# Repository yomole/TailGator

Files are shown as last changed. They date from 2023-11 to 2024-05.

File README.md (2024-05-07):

# [TailGator](https://github.com/yomole/TailGator)

> [!NOTE]
> - If you are a student who has requested to continue this project as part of senior design for MIL, please fork this repository for your project and update the submodules link inside of the MIL Electrical Team SubjuGator 9 repository.
> - Feel free to reach out to the project's hardware designer (Yovany Molina) for any questions you might have.
> - Assembled boards and spare PCBs and parts may still be in the lab.
> - Good Luck!

# Introduction

The TailGator Interconnect System (TGIS) project provides a modular connection system and standard for easily connecting, replacing, and upgrading underwater robotics hardware in space-constrained robotics designs. 
Several other standards exist for modular electronics hardware, including:

- [Adafruit Feather Specification](https://learn.adafruit.com/adafruit-feather/feather-specification)
- [Sparkfun MicroMod Specification](https://www.sparkfun.com/micromod)
- [Arduino Shield Specificaton](https://learn.sparkfun.com/tutorials/arduino-shields-v2)
- [PCI-e Specification](https://pcisig.com/)

However, no single standard contains the pin density, physical dimensions, signal integrity, power delivery, and cost effectiveness we are looking for. The TailGator Interconnect System aims to solve this problem for the Machine Intelligence Laboratories' [SubjuGator 9 Autonomous Underwater Vehicle](http://subjugator.org/?page_id=3390) platform while making the design open source to help the robotics community.

Our production release demonstration can be found here: https://youtu.be/vW_x0FsKn2Q

# Electrical Specifications

The current design of TGIS can supply:
- 3.3V @ 4A (13.3W)
- 5V @ 4A (20W)

Reserved lines may be used to supplement the 3.3V or 5V lines. Board designs may also include a 5V to 3.3V LDO regulator to suppliment the 3.3V line on a specific board in the system.

## Pinout

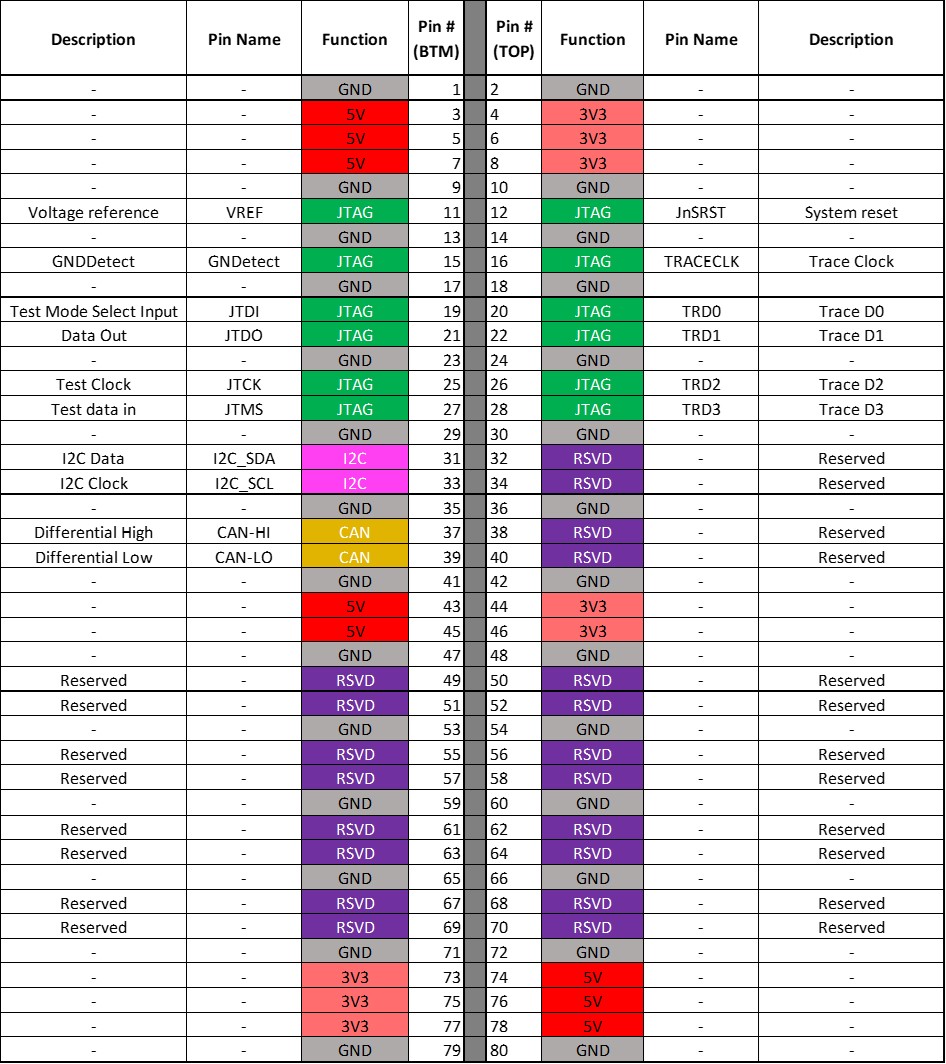
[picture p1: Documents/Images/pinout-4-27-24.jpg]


# Hardware

Currently, the project contains Altium schematics and layouts for three boards used for power, communications, and alpha-build testing. These can be found in the `PCB/TailGator Interconnect System` folder:
- Power Input Board (`TGIS Main`) **V1**: Accepts power for the 3.3V and 5V rails used for TGIS boards while regulating it against reverse polarity and overvoltage. Also offers overcurrent protection.
- USB to CAN Board (`TGIS USB to CAN`) **V1**: Transcribes USB serial messages into CAN packets that are sent to all connected boards in the TGIS system. This board has inputs for JTAG, external CAN connections using RJ45, and SWD for debugging the board's RP2040 microcontroller.
- Breakout Board (`TGIS Breakout`) **V1**: Allows access to the TGIS connector lines using typical 0.1" (2.54mm) headers. This is going to be used for alpha-build testing of the different features currently implemented across all produced boards.  

Other folders contain incomplete designs for other planned boards.

## Documentation

For those without access to [Altium Designer](https://www.altium.com/altium-designer), [Altium Designer Viewer](https://www.altium.com/altium-designer-viewer), or similar compatible applications, documentation for each produced hardware design is available under the `Project Outputs` folder for each respective project. Links are also provided here for convienience:
- [Power Distribution Board](<PCB/TailGator Interconnect System/TGIS Main/Project Outputs for TGIS Power Distribution Board/TGIS.PDF>)
- [USB to CAN Board](<PCB/TailGator Interconnect System/TGIS USB to CAN/TGIS USB to CAN/Project Outputs for TGIS USB to CAN/TGIS.PDF>)
- [System Status Board](<PCB/TailGator Interconnect System/TGIS System Status/Project Outputs for TGIS System Status/TGIS.PDF>)
- [Termination Board](<PCB/TailGator Interconnect System/TGIS CAN Termination/Project Outputs for TGIS CAN Termination/TGIS.PDF>)
- [Breakout Board](<PCB/TailGator Interconnect System/TGIS Breakout/TGIS Breakout/Project Outputs for TGIS Breakout/TGIS.PDF>)
- Handwritten [Development Notes](<Documents/Research/Backplane.pdf>) taken throughout the project are also available in PDF format.

## Libraries

The Altium libraries used for the project have been compiled into an integrated library for use with your own projects involving the TailGator Interconnect System. You may find `TGIS.intlib` file in `PCB/Library/Project Outputs for TGIS`.

## Simulations

There are LTSpice simulations for some parts of the circuits we designed. Libraries used are included.

- `3V3_Protection.asc` is an LTSpice simulation of the 3.3V protection circuits in the Power Input Board. This circuit contains reverse polarity protection, overcurrent protection, and overvoltage protection.
- `5V_Protection.asc` is an LTSpice simulation of the 5V protection circuits in the Power Input Board. This circuit contains reverse polarity protection, overcurrent protection, and overvoltage protection.

### LTSpice Libraries

The libraries in the simulations folder are used for some of the components in the LTSpice circuits.

- `fuse2.lib` is a library of fuses compiled by user aurvii based on a fuse model by Helmut Sennewald. It can be found in the [Official LTSpice Support Group](https://groups.io/g/LTspice).
- `st_standard_sensitve_scr` is a library of sensitive and standard SCRs/Thyristors by STMicroelectronics. It can be found [here](https://www.st.com/resource/en/spice_model/standard_sensitive_scr_pspice.zip).
- `Zener_DiodesInc.lib` is a modified version of this [zener diodes library](https://www.diodes.com/productcollection/spicemodels/8345/Zener+Diodes.spice.txt?eid=88) from Diodes Inc with `.ends` statements moved to new lines to appease LTSpice.

All other models used come standard with LTSpiceXVII.

To install these libraries, you must copy and paste them into your LTSpice subcircuit folder. Depending on your version of LTSpice, on Windows machines, this could be:
- `%localappdata%\LTspice\lib\sub`
- `%userprofile%\Documents\LTSpiceXVII\lib\sub`
- `%programfiles%\LTC\LTSpiceXVII\lib\sub`

or other directories.

### Simulation Results

#### 5V_Protection.asc
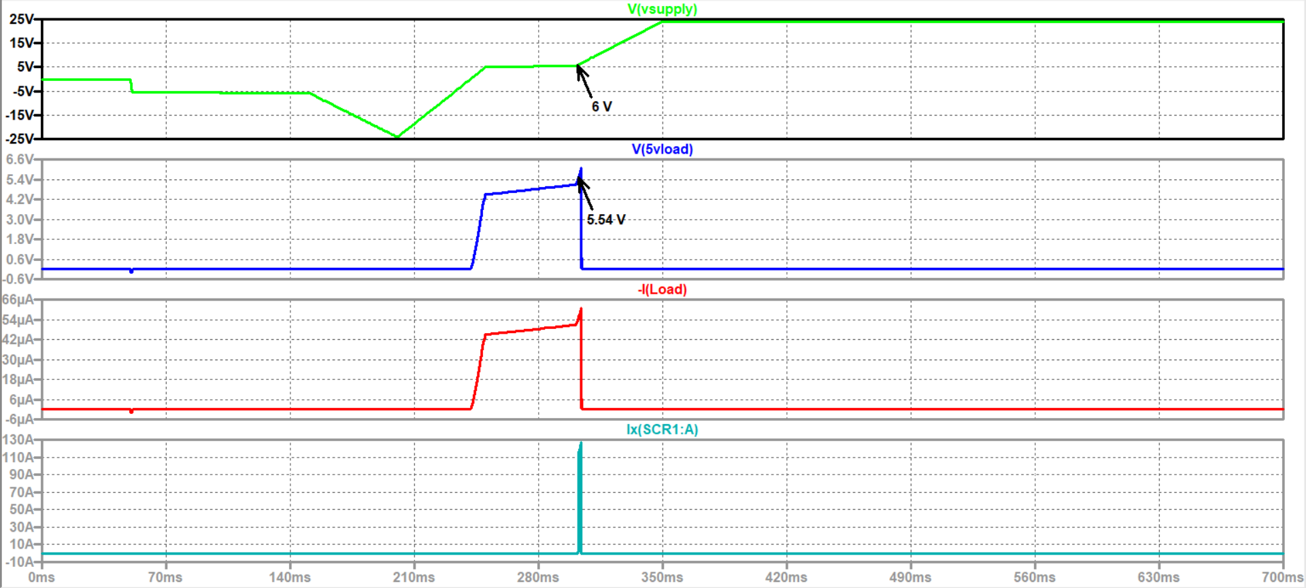
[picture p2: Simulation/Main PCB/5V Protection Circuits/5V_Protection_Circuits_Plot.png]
Plot of 5V protection circuits


#### 3V3_Protection.asc
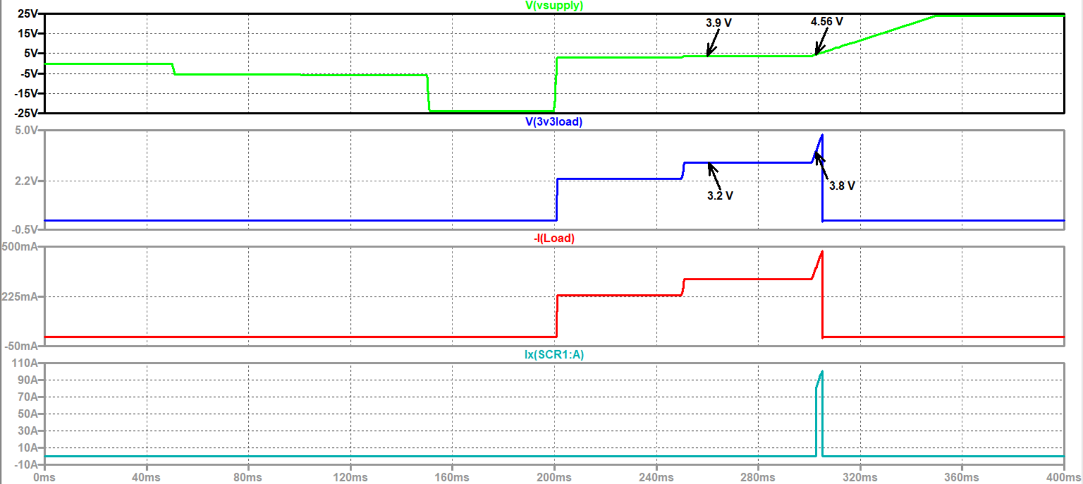
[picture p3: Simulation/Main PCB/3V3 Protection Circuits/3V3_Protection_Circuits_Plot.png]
Plot of 3.3V protection circuits


### Hardware Test Results

### V1

Hardware testing for the power input board was performed using a ODP3122 power supply, DL3021 electric load, and an MSO7014A mixed signal oscilloscope. Most of this equipment was interfaced using python code to send SCPI messages.

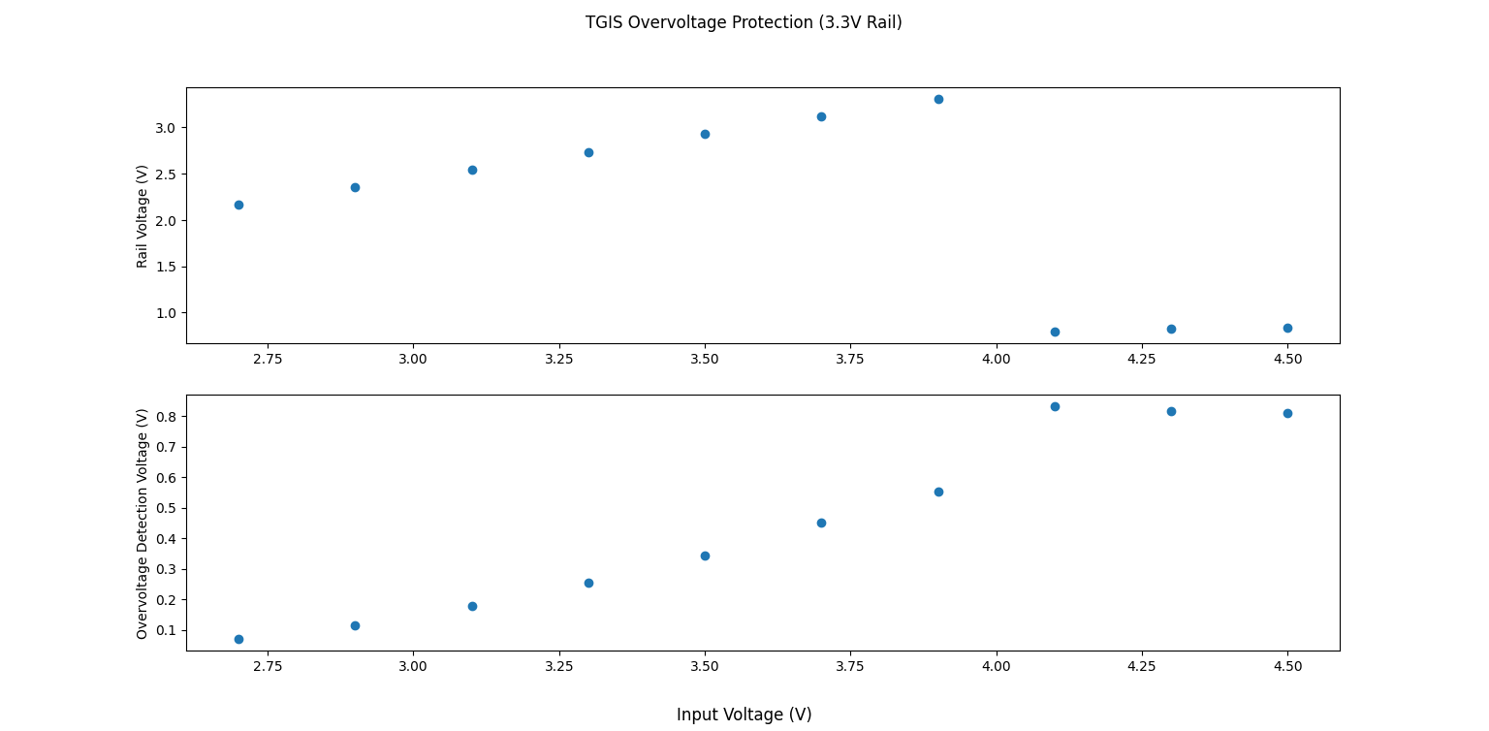
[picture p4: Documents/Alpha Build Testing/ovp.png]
Plot of 3.3V overvoltage protection

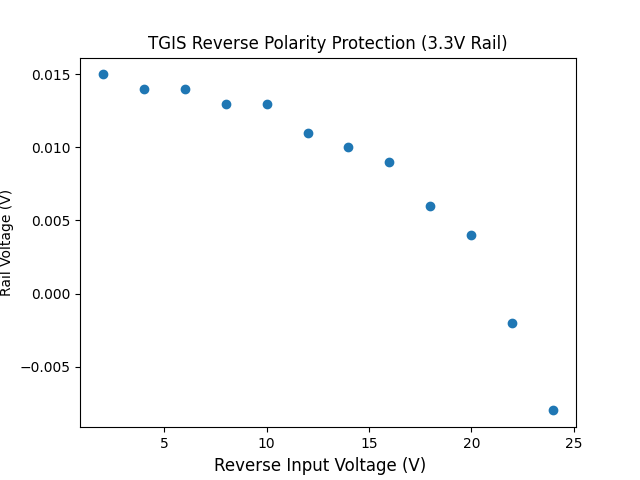
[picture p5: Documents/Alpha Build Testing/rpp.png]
Plot of 3.3V reverse polarity protection


The fuse did work in the overvoltage protection case, but activated after a very long amount of time. We will try to use fast acting automotive fuses in future revisions.

## Known Issues
- The mezzanine connector used has too small of a pitch to be reliably soldered using reflow. We recommend switching to [conan connectors](https://www.digikey.com/en/product-highlight/a/amphenol-fci/conan-lite-1-00-mm-connectors) since they have a slightly larger (1.0mm) pitch. 60 pins should still be enough to have plenty of reserved pins for future expansion.
- The BOM has the wrong SWD connector.
- Some parts on the system status board (like the LEDs) require an active USB connection to function. They should instead be powered from the same source as the RP2040 (which is the selectable power source).
- The reset circuit on the system status board does not function correctly.
- The breakout board should be expanded to have plug and receptacle connections like other boards so it can be used in the front or the back.
- The headers to disable I2C on the termination board should be replaced with 0 ohm resistors that are not placed by default.
- The mounting holes should be M2.5 as MIL has switched to that screw size being the standard for all boards.
- The power distribution board has a higher voltage drop across the protection circuitry, meaning that there is still a problem if bypass mode is used without first checking the input voltage. We recommend keeping the crowbar circuit design from V1.
- CAN signals cannot pass through the USB to CAN board, but can pass through all other boards, including the System Status Board. Further investigation is needed.
- JTAG chaining was never implemented since no microcontrollers on designed boards supported JTAG. They may need buffers between boards for proper operation.
- Some JTAG signals (TRACECLK, TRD*, VREF, GNDDetect, JnSRST) may be omitted from the connector or otherwise tied to a constant value.

# Software
Our work includes the design of firmware for the TGIS's system status board, which can display diagnostic information about the system.

For the production release, the firmware has been fully verified to support all major components on the system status board PCB:
- OLED display, prototyped on the [Adafruit OLED Feather](https://www.adafruit.com/product/4650) and communicating via I2C;
- LIS3DH IMU (tested previously in the Alpha Build);
- Micro SD card reader, using 4-pin SPI to communicate;
- Leak alarm, a piezo buzzer activated via GPIO; and
- Leak detector, prototyped via a push button connected to an input pin on the Feather RP2040.

All of the above components have been updated to work concurrently on `embedded-hal` version 1.0.

We are using the [RTIC Framework](https://rtic.rs/) to provide concurrent sensor access and display interfacing. This app can be seen in the `RTIC_App` directory of this repo.

## Installation

Prerequisites:
- Working Rust toolchain for embedded development on the RP2040 (e.g., capable of running the Embedded Rust lab code)
- Adafruit Feather RP2040
- All of the above major components (LIS3DH, OLED, SD card reader) and connectivity to the feather (jumper cables and/or Feather boards)
- (Note: for testing the CAN demonstration, a pair of RP2040 devices each attached to a CAN transceiver via two GPIO pins for the Rx and Tx lines is required. One device must be flashed with the transmitter code--`CAN_Demo/CAN_Transmsit`--and the other with the receiver code--`CAN_Demo/CAN_Receive`. The transmitter should have a digital input component such as a button attached to the appropriate GPIO pin, and the receiver must be attached to a computer via USB where `minicom` shoud be run to inspect serial output at baud rate 115200.)

Clone this repository: `https://github.com/yomole/TailGator.git`, then open the app (`RTIC_App`) and inspect the code.

From within the app, run `cargo run` from within the `RTIC_App` directory with your Feather RP2040 connected to a debug probe over SWD. This will automatically flash the software to the Feather and run the program with rich debug output.

Alternatively, in .cargo/config, you can set the runner to be `elf2uf2-rs` instead of `probe-rs` by commenting and uncommenting the appropriate lines. `cargo run` will then work with a Feather RP2040 set to receive a UF2 file, but of course you will need a debug probe to see the output.

## Known Issues
1. CAN bus communication has not yet been integrated with the system status board firmware due to a need for more up-to-date CAN drivers.
2. SWD port on the system status board is nonfunctional, and so debug output can only be demonstrated on the testbench via a Feather RP2040 and appropriately wired components. This may require reconfiguring GPIO pin selection for the devices under test.

# Time Tracking

[Google Sheet](https://docs.google.com/spreadsheets/d/1ABE5ELdahlYolHOQ2TSzXDdkT7J0JBhl6qDKFItKDu4/)

# Ackowledgements

This project is made in collaboration with:
- [Machine Intelligence Laboratory](https://mil.ufl.edu/)

Thanks to [Carsten](https://github.com/shulltronics) for supporting our switch to the Rust RTIC framework and for providing a secondary Adafruit Feather RP2040 to use as an SWD debugger, as well as an OLED display and associated connector cable.

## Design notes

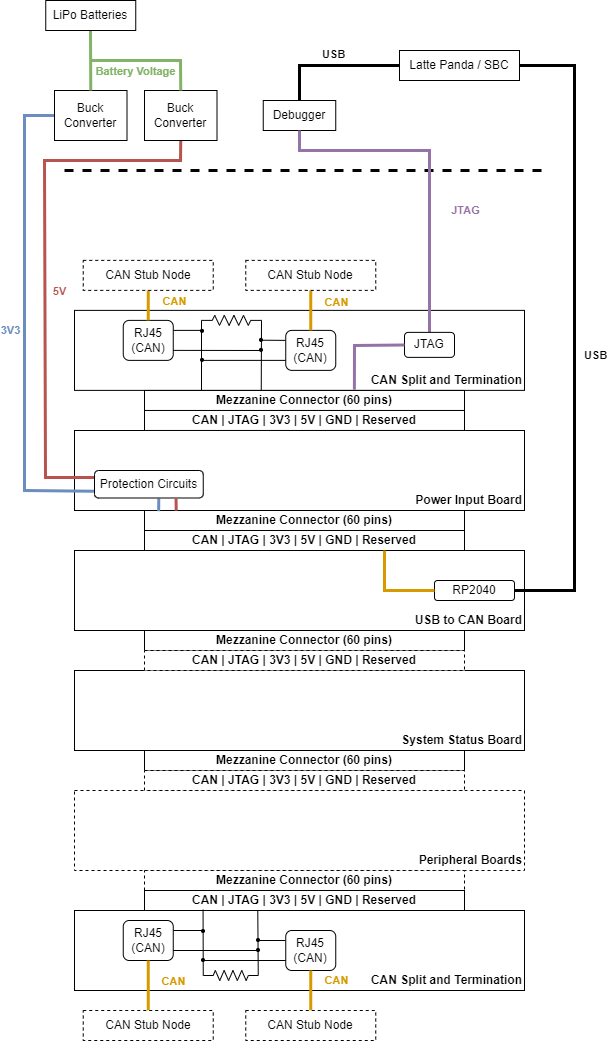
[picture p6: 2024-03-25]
Documents/Images/Block Diagram.png

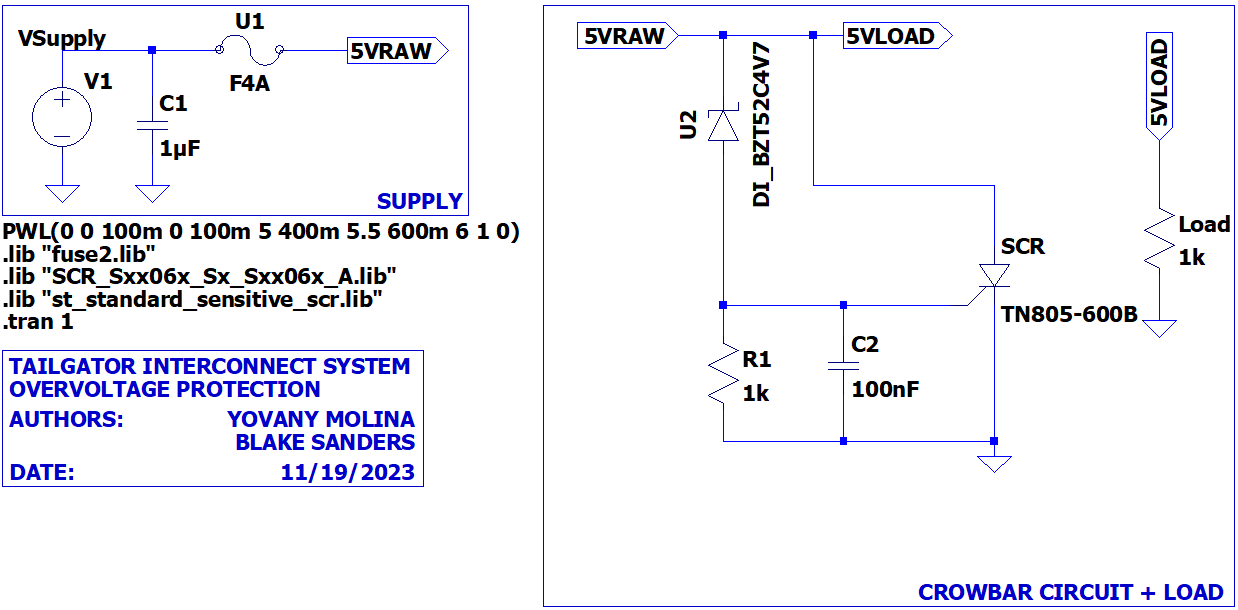
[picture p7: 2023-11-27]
Simulation/Main PCB/5V Protection Circuits/5V_OVP_Circuit.png

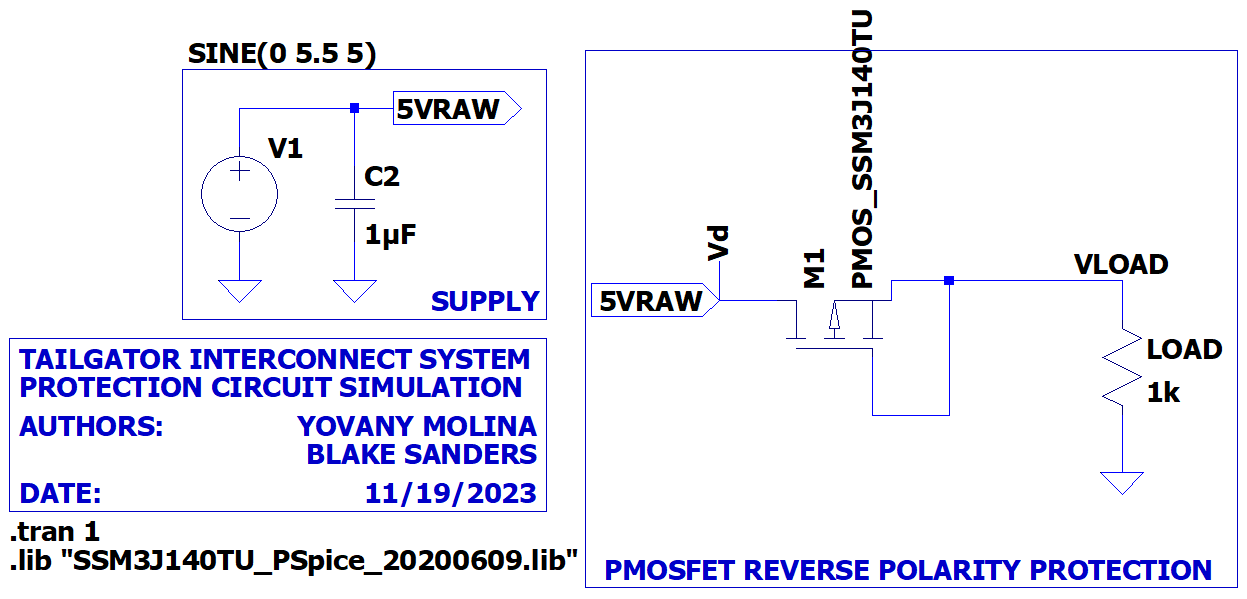
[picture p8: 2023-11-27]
Simulation/Main PCB/5V Protection Circuits/5V_RPP_Circuit.png

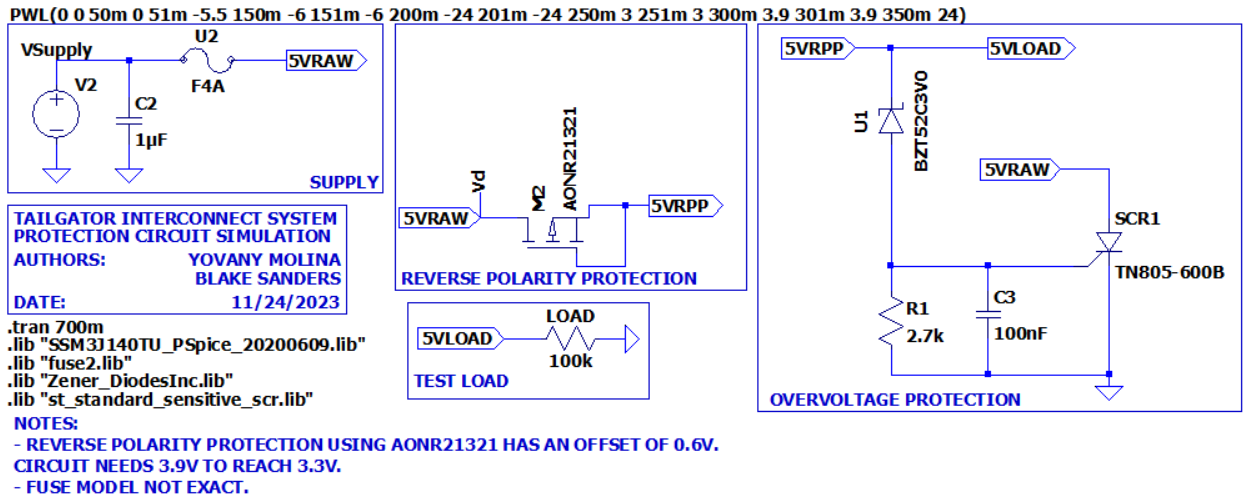
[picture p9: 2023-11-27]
Simulation/Main PCB/3V3 Protection Circuits/3V3_Protection_Circuits.png

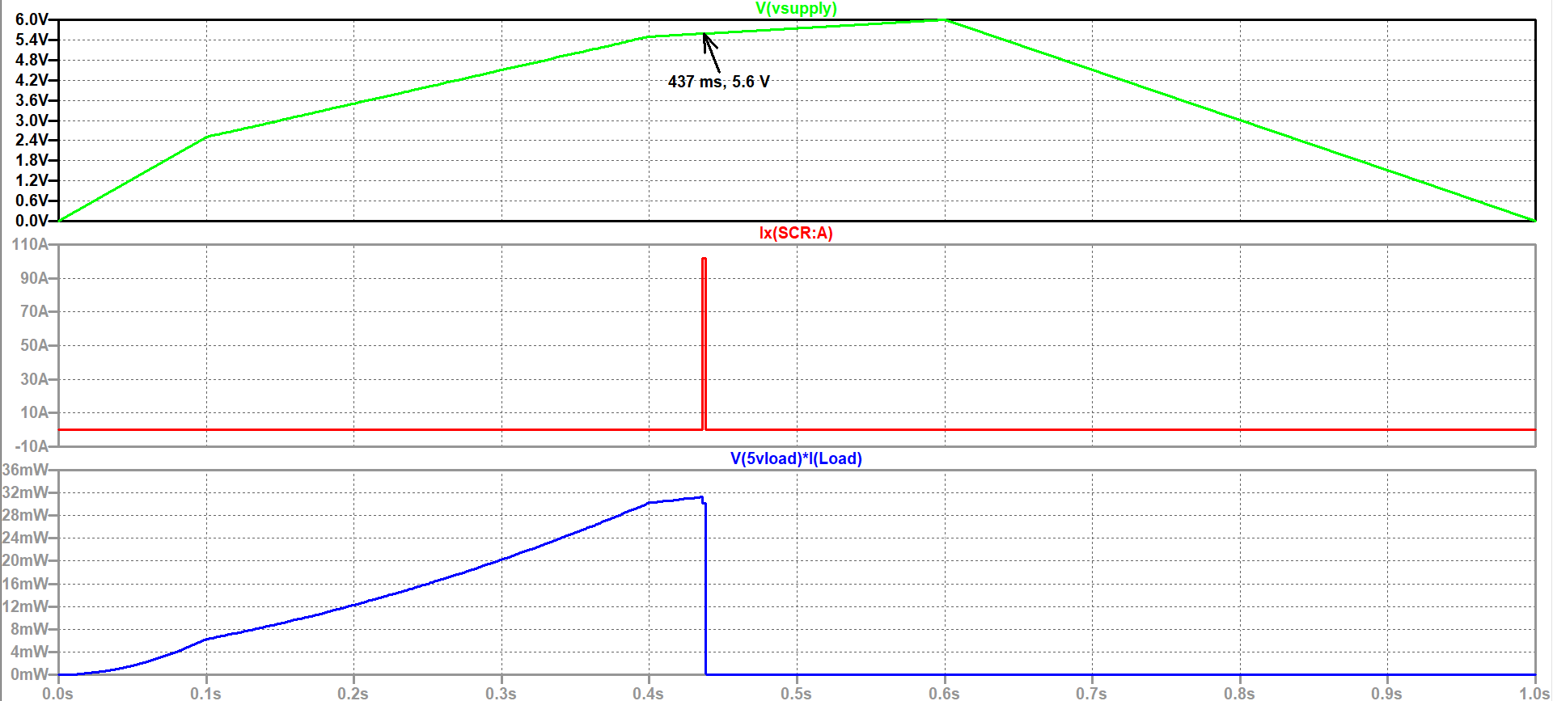
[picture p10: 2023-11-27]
Simulation/Main PCB/5V Protection Circuits/5V_OVP_Plot.png

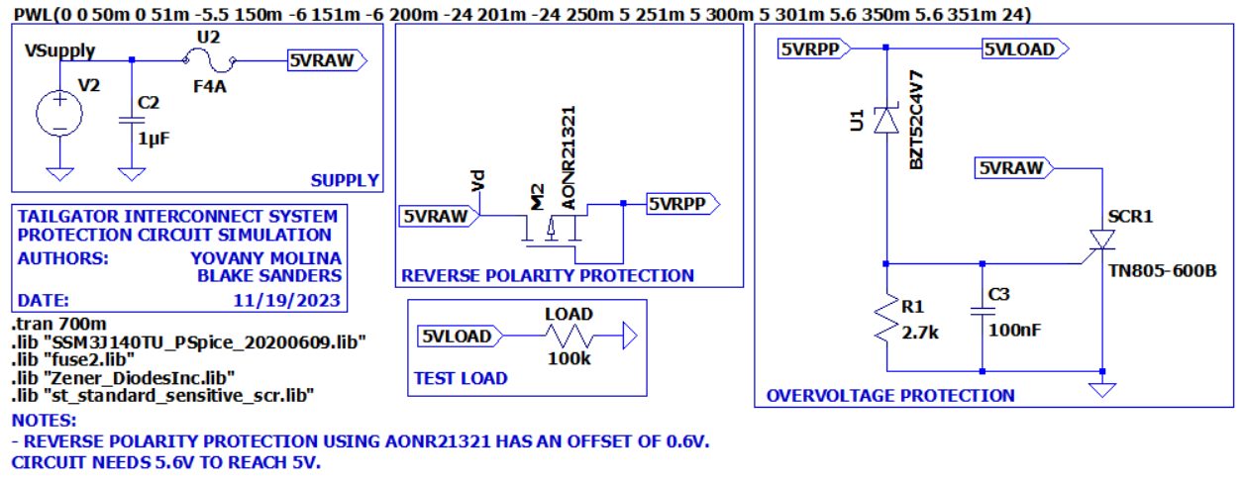
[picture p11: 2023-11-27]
Simulation/Main PCB/5V Protection Circuits/5V_Protection_Circuits.png

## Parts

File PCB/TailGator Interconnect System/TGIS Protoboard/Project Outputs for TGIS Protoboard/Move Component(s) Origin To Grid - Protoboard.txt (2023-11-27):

Move Component(s) Origin to Grid
Filename     : C:\Users\molyo\OneDrive\Desktop\MIL\TailGator\PCB\TailGator Interconnect System\TGIS Protoboard\Protoboard.PcbDoc
Date         : 11/7/2023
Time         : 5:04:12 PM
Time Elapsed : 00:00:00

    Component J?-RAILS (3960mil,2960mil) on Top Layer - Component origin is already ON grid. - Component pads are OFF grid. No action taken.
    SOIC Component J?-10144517-063802LF (3960mil,1460mil) on Top Layer - Component origin is already ON grid. - Component pads are OFF grid. No action taken.
count : 2

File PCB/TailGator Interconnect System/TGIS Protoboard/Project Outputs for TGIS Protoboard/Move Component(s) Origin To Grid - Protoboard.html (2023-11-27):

Date: | 11/7/2023
Time: | 5:04:12 PM
Elapsed Time: | 00:00:00
Filename: | C:\Users\molyo\OneDrive\Desktop\MIL\TailGator\PCB\TailGator Interconnect System\TGIS Protoboard\Protoboard.PcbDoc
Component J?-RAILS (3960mil,2960mil) on Top Layer - Component origin is already ON grid. - Component pads are OFF grid. No action taken.
SOIC Component J?-10144517-063802LF (3960mil,1460mil) on Top Layer - Component origin is already ON grid. - Component pads are OFF grid. No action taken.

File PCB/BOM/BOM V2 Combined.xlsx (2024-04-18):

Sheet: COMBINED PT2
Line # | Project Designator | Quantity | Supplier Order Qty 1 | Manufacturer | Manufacturer Part Number | Supplier Part Number | STAT?
1 | *PDB* C1, C2 | *TERM* C1, C2 | *U2C* C2, C3, C4, C5, C6, C7, C8, C9, C11, C12, C13, C16, C17 | *STAT* C2, C3, C4, C5, C6, C7, C8, C9, C11, C12, C13, C18, C19, C20, C21, C22 | 33 | 35 | Yageo | CC0603KRX7R7BB104 | 311-1088-1-ND | YES
2 | *PDB* D1 | 1 | 1 | Diodes | BZT52C3V0-7-F | BZT52C3V0-FDICT-ND | NO
3 | *PDB* D3 | 1 | 1 | Diodes | BZT52C4V7-13-F | BZT52C4V7-13-FDICT-ND | NO
4 | *PDB* D5 | *U2C* D2, LED2 | *STAT* D3, LED2 | 5 | 5 | Wurth Electronics | 150060YS75000 | 732-4981-1-ND | YES
5 | *PDB* D6 | *U2C* LED1 | *STAT* D1, LED1 | 4 | 4 | Wurth Electronics | 150060RS75000 | 732-4978-1-ND | YES
6 | *PDB* J1 | *TERM* J1 | *U2C* J1 | *STAT* J1 | 4 | 5 | Amphenol ICC / FCI | 10144517-081802LF | 609-5437-1-ND | YES
7 | *PDB* J2 | 1 | 1 | Amphenol Communications Solutions | 10144518-081802LF | 609-5453-1-ND | NO
8 | *PDB* J3, J4 | 2 | 2 | TE Connectivity | 1877285-2 | A99845-ND | NO
9 | *PDB* Q1, Q2 | 2 | 2 | Alpha & Omega Semiconductor | AONR21321 | 785-1797-1-ND | NO
10 | *PDB* R1, R2 | 2 | 2 | Yageo | RC0603FR-073K3L | 311-3.30KHRCT-ND | NO
11 | *PDB* R3, R4 | *TERM* R1, R2, R3, R4, R5, R6 | *U2C* R4, R6, R8, R13, R14 | *STAT* R4, R6, R8, R9, R10, R11, R12, R15 | 21 | 27 | Yageo | RC0603FR-071KL | 311-1.00KHRCT-ND | YES
12 | *TERM* C3, C4 | 2 | 4 | Yageo | CC0603JPX7R9BB472 | 13-CC0603JPX7R9BB472CT-ND | NO
13 | *TERM* J2 | *U2C* J2 | *STAT* J2 | 3 | 4 | Amphenol Communications Solutions | 10144518-083802LF | 609-5455-1-ND | YES
14 | *TERM* J3, J4, J5, J6 | 4 | 8 | Molex | 0353630260 | WM18931-ND | NO
15 | *TERM* R7, R8, R13, R14 | 4 | 8 | Yageo | RC0603JR-070RL | 311-0.0GRCT-ND | NO
16 | *TERM* R9, R10, R11, R12 | 4 | 8 | Yageo | RC0603FR-0760R4L | 311-60.4HRCT-ND | NO
17 | *TERM* U1, U2 | 2 | 4 | NXP Semiconductors | PCA9515ADP.118 | 568-1032-1-ND | NO
18 | *U2C* J5 | 1 | 1 | Adam Equipment | PH2RA-08-UA | 2057-PH2RA-08-UA-ND | NO
19 | *STAT* J5 | 1 | 1 | GCT | MEM2052-00-195-00-A | 2073-MEM2052-00-195-00-ACT-ND | YES
20 | *STAT* J6 | 1 | 1 | Adafruit Industries | 4650 | 1528-4650-ND | YES
21 | *STAT* J7 | 1 | 1 | Molex | 35363-0360 | WM18932-ND | YES
22 | *STAT* J8 | 1 | 1 | Molex | 35363-0460 | WM18933-ND | YES
23 | *STAT* Q1 | 1 | 1 | Diodes | DMP3056L-7 | DMP3056L-7DICT-ND | YES
24 | *STAT* Q2 | 1 | 1 | ON Semiconductor / Fairchild | 2N7002W | 2N7002WCT-ND | YES
25 | *STAT* R13, R14 | 2 | 2 | Yageo | RC0603FR-0710KL | 311-10.0KHRCT-ND | YES
26 | *STAT* R17, R18 | 2 | 2 | Stackpole Electronics | RMCF0603JT10K0 | RMCF0603JT10K0CT-ND | YES
27 | *STAT* U4 | 1 | 1 | CUI Devices | CMI-9705-0380-SMT-TR | 102-CMI-9705-0380-SMT-CT-ND | YES
28 | *STAT* U5 | 1 | 1 | Diodes | 74LVC1G17SE-7 | 74LVC1G17SE-7CT-ND | YES
29 | *STAT* U7 | 1 | 1 | STMicroelectronics | LIS3DHTR | 497-10613-1-ND | YES
30 | *U2C* C1, C10, C19, C20 | *STAT* C1, C10, C16, C17 | 8 | 8 | Yageo | CC0603KRX7R7BB105 | 311-1446-1-ND | YES
31 | *U2C* C14, C15 | *STAT* C14, C15 | 4 | 4 | Yageo | CC0603JRNPO9BN270 | 311-1063-1-ND | YES
32 | *U2C* D1 | *STAT* D2 | 2 | 2 | Wurth Electronics | 150060VS75000 | 732-4980-1-ND | YES
33 | *U2C* J3 | *STAT* J3 | 2 | 2 | Global Connector Technology | USB4105-GF-A | 2073-USB4105-GF-ACT-ND | YES
34 | *U2C* J4 | *STAT* J4 | 2 | 2 | CNC Tech | 3221-10-0300-00 | 1175-1735-ND | YES
35 | *U2C* Q1, Q2 | *STAT* Q3, Q4 | 4 | 4 | ON Semiconductor | MMUN2235LT1G | MMUN2235LT1GOSCT-ND | YES
36 | *U2C* R1, R2 | *STAT* R1, R2 | 4 | 4 | Yageo | RC0603FR-075K1L | 311-5.10KHRCT-ND | YES
37 | *U2C* R5, R7 | *STAT* R5, R7 | 4 | 4 | Yageo | RC0603FR-0727R4L | 311-27.4HRCT-ND | YES
38 | *U2C* R11, R12 | *STAT* R16, R19, R20 | 5 | 5 | Yageo | RC0603FR-07270RL | 311-270HRCT-ND | YES
39 | *U2C* SW1, SW2 | *STAT* SW1, SW2 | 4 | 4 | ITT C&K | PTS810SJK250SMTRLFS | CKN10503CT-ND | YES
40 | *U2C* SW3 | *STAT* SW3 | 2 | 2 | ITT C&K | JS202011SCQN | 401-2002-1-ND | YES
41 | *U2C* U1 | *STAT* U1 | 2 | 2 | Raspberry Pi | SC0914(13) | 2648-SC0914(13)CT-ND | YES
42 | *U2C* U2 | *STAT* U2 | 2 | 2 | Winbond | W25Q128JVSIQ TR | W25Q128JVSIQCT-ND | YES
43 | *U2C* U3 | *STAT* U6 | 2 | 2 | Texas Instruments | TCAN1057ADDFRQ1 | 296-TCAN1057ADDFRQ1CT-ND | YES
44 | *U2C* U4 | *STAT* U3 | 2 | 2 | Texas Instruments | TLV75733PDRVR | 296-49281-1-ND | YES
45 | *U2C* X1 | *STAT* X1 | 2 | 2 | Abracon | ABLS-12.000MHZ-B2-T | 535-9067-1-ND | YES

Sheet: CHECK
Index | Quantity | Part Number | Manufacturer Part Number | Description | Customer Reference | Available | Backorder | Unit Price | Extended Price USD
1 | 15 | F988-ND | 0297004.WXNV | FUSE AUTOMOTIVE 4A 32VDC BLADE |  | 15 | 0 | 0.325 | 4.88
2 | 2 | W25Q128JVSIQCT-ND | W25Q128JVSIQ TR | IC FLASH 128MBIT SPI/QUAD 8SOIC | STAT V1 U2 | 2 | 0 | 1.78 | 3.56
3 | 2 | 497-10613-1-ND | LIS3DHTR | ACCEL 2-16G I2C/SPI 16LGA | STAT V1 U7 | 2 | 0 | 2.26 | 4.52
4 | 2 | 535-9067-1-ND | ABLS-12.000MHZ-B2-T | CRYSTAL 12.0000MHZ 18PF SMD | STAT V1 X1 | 2 | 0 | 0.24 | 0.48
5 | 2 | 296-TCAN1057ADDFRQ1CT-ND | TCAN1057ADDFRQ1 | IC TRANSCEIVER HALF 1/1 TSOT23-8 | STAT V1 U6 | 2 | 0 | 0.83 | 1.66
6 | 2 | 2648-SC0914(13)CT-ND | SC0914(13) | IC MCU 32B EXT MEM 56QFN RP2040 | STAT V1 U1 | 2 | 0 | 0.7 | 1.40
7 | 2 | 102-CMI-9705-0380-SMT-CT-ND | CMI-9705-0380-SMT-TR | BUZZER MAGNETIC 3V 9.7X9.7MM SMD | STAT V1 U4 | 2 | 0 | 1.77 | 3.54
8 | 2 | 74LVC1G17SE-7CT-ND | 74LVC1G17SE-7 | IC BUF NON-INVERT 5.5V SOT353 | STAT V1 U5 | 2 | 0 | 0.27 | 0.54
9 | 2 | 296-49281-1-ND | TLV75733PDRVR | IC REG LINEAR 3.3V 1A 6WSON | STAT V1 U3 | 2 | 0 | 0.46 | 0.92
10 | 2 | 401-2002-1-ND | JS202011SCQN | SWITCH SLIDE DPDT 300MA 6V | STAT V1 SW3 | 2 | 0 | 0.73 | 1.46
11 | 4 | MMUN2235LT1GOSCT-ND | MMUN2235LT1G | TRANS PREBIAS NPN 50V SOT23-3 | STAT V1 Q3, Q4 | 4 | 0 | 0.13 | 0.52
12 | 2 | WM18933-ND | 0353630460 | CONN HEADER R/A 4POS 2MM | STAT V1 J8 | 2 | 0 | 0.64 | 1.28
13 | 4 | CKN10503CT-ND | PTS810 SJK 250 SMTR LFS | SWITCH TACTILE SPST-NO 0.05A 16V | STAT V1 SW1, SW2 | 4 | 0 | 0.34 | 1.36
14 | 10 | RMCF0603JT10K0CT-ND | RMCF0603JT10K0 | RES 10K OHM 5% 1/10W 0603 | STAT V1 R17, R18 | 10 | 0 | 0.021 | 0.21
15 | 1 | 1528-4650-ND | 4650 | ADAFRUIT FEATHERWING OLED - 128X | STAT V1 J6 | 1 | 0 | 14.95 | 14.95
16 | 2 | DMP3056L-7DICT-ND | DMP3056L-7 | MOSFET P-CH 30V 4.3A SOT23 | STAT V1 Q1 | 2 | 0 | 0.41 | 0.82
17 | 10 | 311-270HRCT-ND | RC0603FR-07270RL | RES 270 OHM 1% 1/10W 0603 | STAT V1 R16, R19, R20 | 10 | 0 | 0.019 | 0.19
18 | 16 | 311-1.00KHRCT-ND | RC0603FR-071KL | RES 1K OHM 1% 1/10W 0603 | STAT V1 R4, R6, R8, R9, R10, R11, R12, R15 | 16 | 0 | 0.019 | 0.30
19 | 10 | 311-27.4HRCT-ND | RC0603FR-0727R4L | RES 27.4 OHM 1% 1/10W 0603 | STAT V1 R5, R7 | 10 | 0 | 0.02 | 0.20
20 | 10 | 311-5.10KHRCT-ND | RC0603FR-075K1L | RES 5.1K OHM 1% 1/10W 0603 | STAT V1 R1, R2 | 10 | 0 | 0.019 | 0.19
21 | 2 | 2N7002WCT-ND | 2N7002W | MOSFET N-CH 60V 310MA SC70 | STAT V1 Q2 | 2 | 0 | 0.43 | 0.86
22 | 2 | WM18932-ND | 0353630360 | CONN HEADER R/A 3POS 2MM | STAT V1 J7 | 2 | 0 | 0.43 | 0.86
23 | 2 | 2073-MEM2052-00-195-00-ACT-ND | MEM2052-00-195-00-A | MICRO SD PUSH PUSH, OPEN, SMT, 1 | STAT V1 J5 | 2 | 0 | 1.2 | 2.40
24 | 10 | 311-10.0KHRCT-ND | RC0603FR-0710KL | RES 10K OHM 1% 1/10W 0603 | STAT V1 R13, R14 | 10 | 0 | 0.019 | 0.19
25 | 2 | 2073-USB4105-GF-ACT-ND | USB4105-GF-A | CONN RCP USB2.0 TYP C 24P SMD RA | STAT V1 J3 | 2 | 0 | 0.81 | 1.62
26 | 50 | 311-1088-1-ND | CC0603KRX7R7BB104 | CAP CER 0.1UF 16V X7R 0603 | STAT V1 C2, C3, C4, C5, C6, C7, C8, C9, C11, C12 | 50 | 0 | 0.0238 | 1.19
27 | 2 | 609-5437-1-ND | 10144517-081802LF | CONN RCPT 80POS SMD GOLD | STAT V1 J1 | 2 | 0 | 1.72 | 3.44
28 | 2 | 732-4980-1-ND | 150060VS75000 | LED GREEN CLEAR 0603 SMD | STAT V1 D2 | 2 | 0 | 0.15 | 0.30
29 | 2 | 609-5455-1-ND | 10144518-083802LF | CONN PLUG 80POS SMD GOLD | STAT V1 J2 | 2 | 0 | 1.38 | 2.76
30 | 10 | 311-1063-1-ND | CC0603JRNPO9BN270 | CAP CER 27PF 50V C0G/NPO 0603 | STAT V1 C14, C15 | 10 | 0 | 0.033 | 0.33
31 | 4 | 732-4981-1-ND | 150060YS75000 | LED YELLOW CLEAR 0603 SMD | STAT V1 D3, LED2 | 4 | 0 | 0.15 | 0.60
32 | 4 | 732-4978-1-ND | 150060RS75000 | LED RED CLEAR 0603 SMD | STAT V1 D1, LED1 | 4 | 0 | 0.15 | 0.60
33 | 2 | 535-9067-1-ND | ABLS-12.000MHZ-B2-T | CRYSTAL 12.0000MHZ 18PF SMD | U2C X1 | 2 | 0 | 0.24 | 0.48
34 | 2 | 1175-1735-ND | 3221-10-0300-00 | CONN HEADER SMD 10POS 1.27MM | STAT V1 J4 | 2 | 0 | 0.76 | 1.52
35 | 2 | 1175-1735-ND | 3221-10-0300-00 | CONN HEADER SMD 10POS 1.27MM | U2C J4 | 2 | 0 | 0.76 | 1.52
36 | 10 | 311-1446-1-ND | CC0603KRX7R7BB105 | CAP CER 1UF 16V X7R 0603 | STAT V1 C1, C10, C16, C17 | 10 | 0 | 0.066 | 0.66
37 | 2 | 2648-SC0914(13)CT-ND | SC0914(13) | IC MCU 32B EXT MEM 56QFN RP2040 | U2C U1 | 2 | 0 | 0.7 | 1.40
38 | 2 | 296-TCAN1057ADDFRQ1CT-ND | TCAN1057ADDFRQ1 | IC TRANSCEIVER HALF 1/1 TSOT23-8 | U2C U3 | 2 | 0 | 0.83 | 1.66
39 | 4 | CKN10503CT-ND | PTS810 SJK 250 SMTR LFS | SWITCH TACTILE SPST-NO 0.05A 16V | U2C SW1, SW2 | 4 | 0 | 0.34 | 1.36
40 | 10 | 311-5.10KHRCT-ND | RC0603FR-075K1L | RES 5.1K OHM 1% 1/10W 0603 | U2C R1, R2 | 10 | 0 | 0.019 | 0.19
41 | 2 | W25Q128JVSIQCT-ND | W25Q128JVSIQ TR | IC FLASH 128MBIT SPI/QUAD 8SOIC | U2C U2 | 2 | 0 | 1.78 | 3.56
42 | 2 | 296-49281-1-ND | TLV75733PDRVR | IC REG LINEAR 3.3V 1A 6WSON | U2C U4 | 2 | 0 | 0.46 | 0.92
43 | 10 | 311-27.4HRCT-ND | RC0603FR-0727R4L | RES 27.4 OHM 1% 1/10W 0603 | U2C R5, R7 | 10 | 0 | 0.02 | 0.20
44 | 2 | 732-4978-1-ND | 150060RS75000 | LED RED CLEAR 0603 SMD | U2C LED1 | 2 | 0 | 0.15 | 0.30
45 | 2 | 2073-USB4105-GF-ACT-ND | USB4105-GF-A | CONN RCP USB2.0 TYP C 24P SMD RA | U2C J3 | 2 | 0 | 0.81 | 1.62
46 | 2 | 2057-PH2RA-08-UA-ND | PH2RA-08-UA | CONN HEADER R/A 8POS 2.54MM | U2C J5 | 2 | 0 | 0.24 | 0.48
47 | 2 | 609-5455-1-ND | 10144518-083802LF | CONN PLUG 80POS SMD GOLD | U2C J2 | 2 | 0 | 1.38 | 2.76
48 | 4 | 732-4981-1-ND | 150060YS75000 | LED YELLOW CLEAR 0603 SMD | U2C D2, LED2 | 4 | 0 | 0.15 | 0.60
49 | 2 | 401-2002-1-ND | JS202011SCQN | SWITCH SLIDE DPDT 300MA 6V | U2C SW3 | 2 | 0 | 0.73 | 1.46
50 | 4 | MMUN2235LT1GOSCT-ND | MMUN2235LT1G | TRANS PREBIAS NPN 50V SOT23-3 | U2C Q1, Q2 | 4 | 0 | 0.13 | 0.52
51 | 10 | 311-270HRCT-ND | RC0603FR-07270RL | RES 270 OHM 1% 1/10W 0603 | U2C R11, R12 | 10 | 0 | 0.019 | 0.19
52 | 10 | 311-1063-1-ND | CC0603JRNPO9BN270 | CAP CER 27PF 50V C0G/NPO 0603 | U2C C14, C15 | 10 | 0 | 0.033 | 0.33
53 | 10 | 311-1.00KHRCT-ND | RC0603FR-071KL | RES 1K OHM 1% 1/10W 0603 | U2C R4, R6, R8, R13, R14 | 10 | 0 | 0.019 | 0.19
54 | 10 | 311-3.30KHRCT-ND | RC0603FR-073K3L | RES 3.3K OHM 1% 1/10W 0603 | PDB V2 R1, R2 | 10 | 0 | 0.019 | 0.19
55 | 2 | 609-5437-1-ND | 10144517-081802LF | CONN RCPT 80POS SMD GOLD | U2C J1 | 2 | 0 | 1.72 | 3.44
56 | 4 | 754-1123-1-ND | APT1608SURCK | LED RED CLEAR CHIP SMD | PDB V2 LED1, LED2 | 4 | 0 | 0.29 | 1.16
57 | 2 | 609-5453-1-ND | 10144518-081802LF | CONN PLUG 80POS SMD GOLD | PDB V2 J2 | 2 | 0 | 1.89 | 3.78
58 | 2 | 732-4980-1-ND | 150060VS75000 | LED GREEN CLEAR 0603 SMD | U2C D1 | 2 | 0 | 0.15 | 0.30
59 | 8 | 568-1032-1-ND | PCA9515ADP,118 | IC REDRIVER I2C 2CH 8TSSOP | TERMV1 U1, U2 | 8 | 0 | 1.53 | 12.24
60 | 10 | 311-1446-1-ND | CC0603KRX7R7BB105 | CAP CER 1UF 16V X7R 0603 | U2C C1, C10, C19, C20 | 10 | 0 | 0.066 | 0.66
61 | 4 | A99845-ND | 1877285-2 | CONN HEADER VERT 2POS 3.96MM | PDB V2 J3, J4 | 4 | 0 | 0.31 | 1.24
62 | 16 | WM18931-ND | 0353630260 | CONN HEADER R/A 2POS 2MM | TERMV1 J3, J4, J5, J6 | 16 | 0 | 0.315 | 5.04
63 | 10 | 311-1.00KHRCT-ND | RC0603FR-071KL | RES 1K OHM 1% 1/10W 0603 | PDB V2 R3, R4 | 10 | 0 | 0.019 | 0.19
64 | 2 | BZT52C4V7-13-FDICT-ND | BZT52C4V7-13-F | DIODE ZENER 4.7V 500MW SOD123 | PDB V2 D3 | 2 | 0 | 0.21 | 0.42
65 | 16 | 311-0.0GRCT-ND | RC0603JR-070RL | RES 0 OHM JUMPER 1/10W 0603 | TERMV1 R7, R8, R13, R14 | 16 | 0 | 0.015 | 0.24
66 | 16 | 311-60.4HRCT-ND | RC0603FR-0760R4L | RES 60.4 OHM 1% 1/10W 0603 | TERMV1 R9, R10, R11, R12 | 16 | 0 | 0.019 | 0.30
67 | 10 | 311-1088-1-ND | CC0603KRX7R7BB104 | CAP CER 0.1UF 16V X7R 0603 | TERMV1 C1, C2 | 10 | 0 | 0.042 | 0.42
68 | 2 | 609-5437-1-ND | 10144517-081802LF | CONN RCPT 80POS SMD GOLD | PDB V2 J1 | 2 | 0 | 1.72 | 3.44
69 | 4 | 609-5437-1-ND | 10144517-081802LF | CONN RCPT 80POS SMD GOLD | TERMV1 J1 | 4 | 0 | 1.72 | 6.88
70 | 4 | 609-5455-1-ND | 10144518-083802LF | CONN PLUG 80POS SMD GOLD | TERMV1 J2 | 4 | 0 | 1.38 | 5.52
71 | 4 | 785-1797-1-ND | AONR21321 | MOSFET P-CH 30V 24A 8DFN | PDB V2 Q1, Q2 | 4 | 0 | 0.44 | 1.76
72 | 24 | 311-1.00KHRCT-ND | RC0603FR-071KL | RES 1K OHM 1% 1/10W 0603 | TERMV1 R1, R2, R3, R4, R5, R6 | 24 | 0 | 0.019 | 0.46
73 | 2 | BZT52C3V0-FDICT-ND | BZT52C3V0-7-F | DIODE ZENER 3V 500MW SOD123 | PDB V2 D1 | 2 | 0 | 0.21 | 0.42
74 | 10 | 13-CC0603JPX7R9BB472CT-ND | CC0603JPX7R9BB472 | CAP CER 4700PF 50V X7R 0603 | TERMV1 C3, C4 | 10 | 0 | 0.069 | 0.69
75 | 26 | 311-1088-1-ND | CC0603KRX7R7BB104 | CAP CER 0.1UF 16V X7R 0603 | U2C C2, C3, C4, C5, C6, C7, C8, C9, C11, C12, C1 | 26 | 0 | 0.042 | 1.09
76 | 4 | 311-1088-1-ND | CC0603KRX7R7BB104 | CAP CER 0.1UF 16V X7R 0603 | PDB V2 C1, C2 | 4 | 0 | 0.1 | 0.40

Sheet: COMBINED PT1
Line # | Name | Description | Designator | Project Designator | Quantity | Supplier Order Qty 1 | Emergency Order Qty | Manufacturer | Manufacturer Part Number | Supplier | Supplier Part Number | Supplier Unit Price | Supplier Subtotal
1 | 100nF | Ceramic Capacitor, Multilayer, Cera | C1, C2 | *PDB* C1, C2 | 2 | 4 | 2 | Yageo | CC0603KRX7R7BB104 | Digikey | 311-1088-1-ND | 0.1 | 0.4
2 | 3V0 | DIODE ZENER 3.0V 500MW SOD123 | D1 | *PDB* D1 | 1 | 2 | 1 | Diodes | BZT52C3V0-7-F | Digikey | BZT52C3V0-FDICT-ND | 0.21 | 0.42
3 | 4V7 | DIODE ZENER 4.7V 500MW SOD123 | D3 | *PDB* D3 | 1 | 2 | 1 | Diodes | BZT52C4V7-13-F | Digikey | BZT52C4V7-13-FDICT-ND | 0.21 | 0.42
4 | YELLOW | Single Color LED, Yellow, Water Cle | D5 | *PDB* D5 | 1 | 2 | 1 | Wurth Electronics | 150060YS75000 | Digikey | 732-4981-1-ND | 0.15 | 0.3
5 | RED | Single Color LED, Red, Water Clear, | D6 | *PDB* D6 | 1 | 2 | 1 | Wurth Electronics | 150060RS75000 | Digikey | 732-4978-1-ND | 0.15 | 0.3
6 | Fuse Holder | Fuse Holder 30 A 500V 1 Circuit Blade Through Hole | F1, F2 | *PDB* F1, F2 | 2 | 4 | 2 | Keystone Electronics | 3568 | Future Electronics | 4264032 | 0.98 | 3.92
7 | 10144517-081802LF | CONN RCPT 1 80POS SMD GOLD | J1 | *PDB* J1 | 1 | 2 | 1 | Amphenol ICC / FCI | 10144517-081802LF | Digikey | 609-5437-1-ND | 1.72 | 3.44
8 | 10144518-081802LF | CONN PLUG 1 80POS SMD GOLD | J2 | *PDB* J2 | 1 | 2 | 1 | Amphenol Communications Solutions | 10144518-081802LF | Digikey | 609-5453-1-ND | 1.89 | 3.78
9 | 1877285-2 |  | J3, J4 | *PDB* J3, J4 | 2 | 4 | 2 | TE Connectivity | 1877285-2 | Digikey | A99845-ND | 0.31 | 1.24
10 | AONR21321 | P-Channel 30 V 24A (Tc) 4.1W (Ta), 24W (Tc) Surface Mount 8-DFN-EP (3x3) | Q1, Q2 | *PDB* Q1, Q2 | 2 | 4 | 2 | Alpha & Omega Semiconductor | AONR21321 | Digikey | 785-1797-1-ND | 0.44 | 1.76
11 | 3.3kR | Fixed Resistor, Metal Glaze/thick F | R1, R2 | *PDB* R1, R2 | 2 | 10 | 2 | Yageo | RC0603FR-073K3L | Digikey | 311-3.30KHRCT-ND | 0.019 | 0.19
12 | 1kR | Fixed Resistor, Metal Glaze/thick F | R3, R4 | *PDB* R3, R4 | 2 | 10 | 2 | Yageo | RC0603FR-071KL | Digikey | 311-1.00KHRCT-ND | 0.019 | 0.19
13 | 100nF | Ceramic Capacitor, Multilayer, Cera | C1, C2 | *TERM* C1, C2 | 2 | 10 | 4 | Yageo | CC0603KRX7R7BB104 | Digikey | 311-1088-1-ND | 0.042 | 0.42
14 | 4.7nF | Ceramic Capacitor, Multilayer, Cera | C3, C4 | *TERM* C3, C4 | 2 | 10 | 4 | Yageo | CC0603JPX7R9BB472 | Digikey | 13-CC0603JPX7R9BB472CT-ND | 0.069 | 0.69
15 | 10144517-081802LF | CONN RCPT 1 80POS SMD GOLD | J1 | *TERM* J1 | 1 | 4 | 2 | Amphenol ICC / FCI | 10144517-081802LF | Digikey | 609-5437-1-ND | 1.72 | 6.88
16 | 10144518-083802LF | CONN PLUG 3 80POS SMD GOLD | J2 | *TERM* J2 | 1 | 4 | 2 | Amphenol Communications Solutions | 10144518-083802LF | Digikey | 609-5455-1-ND | 1.38 | 5.52
17 | 0353630260 | Header, Molex, 2mm Pitch Sherlock Header, Single Row, Horizontal, 2 Circuits, Length 3.3mm, 0353630260 | J3, J4, J5, J6 | *TERM* J3, J4, J5, J6 | 4 | 16 | 8 | Molex | 0353630260 | Digikey | WM18931-ND | 0.315 | 5.04
18 | DNP | (DO NOT PLACE) Resistor | R1, R2, R3, R4, R5, R6 | *TERM* R1, R2, R3, R4, R5, R6 | 6 | 24 | 12 | Yageo | RC0603FR-071KL | Digikey | 311-1.00KHRCT-ND | 0.019 | 0.456
19 | 0R | Fixed Resistor, Metal Glaze/thick F | R7, R8, R13, R14 | *TERM* R7, R8, R13, R14 | 4 | 16 | 8 | Yageo | RC0603JR-070RL | Digikey | 311-0.0GRCT-ND | 0.015 | 0.24
20 | 60.4R | Fixed Resistor, Metal Glaze/thick F | R9, R10, R11, R12 | *TERM* R9, R10, R11, R12 | 4 | 16 | 8 | Yageo | RC0603FR-0760R4L | Digikey | 311-60.4HRCT-ND | 0.019 | 0.304
21 | PCA9515ADP | IC REDRIVER I2C 2CH 8TSSOP | U1, U2 | *TERM* U1, U2 | 2 | 8 | 4 | NXP Semiconductors | PCA9515ADP.118 | Digikey | 568-1032-1-ND | 1.53 | 12.24
22 | 1uF | Ceramic Capacitor, Multilayer, Cera | C1, C10, C19, C20 | *U2C* C1, C10, C19, C20 | 4 | 10 | 4 | Yageo | CC0603KRX7R7BB105 | Digikey | 311-1446-1-ND | 0.066 | 0.66
23 | 100nF | Ceramic Capacitor, Multilayer, Cera | C2, C3, C4, C5, C6, C7, C8, C9, C11, C12, C13, C16, C17 | *U2C* C2, C3, C4, C5, C6, C7, C8, C9, C11, C12, C13, C16, C17 | 13 | 26 | 13 | Yageo | CC0603KRX7R7BB104 | Digikey | 311-1088-1-ND | 0.042 | 1.09
24 | 27pF | Ceramic Capacitor, Multilayer, Cera | C14, C15 | *U2C* C14, C15 | 2 | 10 | 2 | Yageo | CC0603JRNPO9BN270 | Digikey | 311-1063-1-ND | 0.033 | 0.33
25 | GREEN | Single Color LED, Bright Green, Wat | D1 | *U2C* D1 | 1 | 2 | 1 | Wurth Electronics | 150060VS75000 | Digikey | 732-4980-1-ND | 0.15 | 0.3
26 | YELLOW | Single Color LED, Yellow, Water Cle | D2, LED2 | *U2C* D2, LED2 | 2 | 4 | 2 | Wurth Electronics | 150060YS75000 | Digikey | 732-4981-1-ND | 0.15 | 0.6
27 | 10144517-081802LF | CONN RCPT 1 80POS SMD GOLD | J1 | *U2C* J1 | 1 | 2 | 1 | Amphenol ICC / FCI | 10144517-081802LF | Digikey | 609-5437-1-ND | 1.72 | 3.44
28 | 10144518-083802LF | CONN PLUG 3 80POS SMD GOLD | J2 | *U2C* J2 | 1 | 2 | 1 | Amphenol Communications Solutions | 10144518-083802LF | Digikey | 609-5455-1-ND | 1.38 | 2.76
29 | USB4105-GF-A | USB-C (USB TYPE-C) USB 2.0 Receptacle Connector 24 (16+8 Dummy) Position Surface Mount, Right Angle; Through Hole | J3 | *U2C* J3 | 1 | 2 | 1 | Global Connector Technology | USB4105-GF-A | Digikey | 2073-USB4105-GF-ACT-ND | 0.81 | 1.62
30 | 3221-10 | Connector Header Surface Mount 10 position 0.050" (1.27mm) | J4 | *U2C* J4 | 1 | 2 | 1 | CNC Tech | 3221-10-0300-00 | Digikey | 1175-1735-ND | 0.76 | 1.52
31 | PH2RA-08-UA | Connector Header Through Hole, Right Angle 8 position 0.100" (2.54mm) | J5 | *U2C* J5 | 1 | 2 | 1 | Adam Equipment | PH2RA-08-UA | Digikey | 2057-PH2RA-08-UA-ND | 0.24 | 0.48
32 | RED | Single Color LED, Red, Water Clear, | LED1 | *U2C* LED1 | 1 | 2 | 1 | Wurth Electronics | 150060RS75000 | Digikey | 732-4978-1-ND | 0.15 | 0.3
33 | MMUN2235LT1G | Small Signal Bipolar Transistor, 0. | Q1, Q2 | *U2C* Q1, Q2 | 2 | 4 | 2 | ON Semiconductor | MMUN2235LT1G | Digikey | MMUN2235LT1GOSCT-ND | 0.13 | 0.52
34 | 5.1kR | Fixed Resistor, Metal Glaze/thick F | R1, R2 | *U2C* R1, R2 | 2 | 10 | 2 | Yageo | RC0603FR-075K1L | Digikey | 311-5.10KHRCT-ND | 0.019 | 0.19
35 | 1kR | Fixed Resistor, Metal Glaze/thick F | R4, R6, R8, R13, R14 | *U2C* R4, R6, R8, R13, R14 | 5 | 10 | 5 | Yageo | RC0603FR-071KL | Digikey | 311-1.00KHRCT-ND | 0.019 | 0.19
36 | 27.4R | Fixed Resistor, Metal Glaze/thick F | R5, R7 | *U2C* R5, R7 | 2 | 10 | 2 | Yageo | RC0603FR-0727R4L | Digikey | 311-27.4HRCT-ND | 0.02 | 0.2
37 | 270R | Fixed Resistor, Metal Glaze/thick F | R11, R12 | *U2C* R11, R12 | 2 | 10 | 2 | Yageo | RC0603FR-07270RL | Digikey | 311-270HRCT-ND | 0.019 | 0.19
38 | PTS810 SJK 250 | Tactile Switch SPST-NO Top Actuated Surface Mount | SW1, SW2 | *U2C* SW1, SW2 | 2 | 4 | 2 | ITT C&K | PTS810SJK250SMTRLFS | Digikey | CKN10503CT-ND | 0.34 | 1.36
39 | JS202011SCQN | Slide Switch DPDT Surface Mount | SW3 | *U2C* SW3 | 1 | 2 | 1 | ITT C&K | JS202011SCQN | Digikey | 401-2002-1-ND | 0.73 | 1.46
40 | RP2040 | ARM® Cortex®-M0+ - Microcontroller IC 32-Bit Dual-Core 133MHz External Program Memory 56-QFN (7x7) | U1 | *U2C* U1 | 1 | 2 | 1 | Raspberry Pi | SC0914(13) | Digikey | 2648-SC0914(13)CT-ND | 0.7 | 1.4
41 | W25Q128JVSIQ | FLASH - NOR Memory IC 128Mbit SPI - Quad I/O, QPI, DTR 133 MHz 8-SOIC | U2 | *U2C* U2 | 1 | 2 | 1 | Winbond | W25Q128JVSIQ TR | Digikey | W25Q128JVSIQCT-ND | 1.78 | 3.56
42 | TCAN1044AV | 1/1 Transceiver Half CANbus TSOT-23-8 | U3 | *U2C* U3 | 1 | 2 | 1 | Texas Instruments | TCAN1057ADDFRQ1 | Digikey | 296-TCAN1057ADDFRQ1CT-ND | 0.83 | 1.66
43 | TLV757P | Linear Voltage Regulator IC Positive Fixed 1 Output 1A 6-WSON (2x2) | U4 | *U2C* U4 | 1 | 2 | 1 | Texas Instruments | TLV75733PDRVR | Digikey | 296-49281-1-ND | 0.46 | 0.92
44 | 12.000MHZ | 12 MHz ±20ppm Crystal 18pF 50 Ohms HC-49/US | X1 | *U2C* X1 | 1 | 2 | 1 | Abracon | ABLS-12.000MHZ-B2-T | Digikey | 535-9067-1-ND | 0.24 | 0.48
45 | 1uF | Ceramic Capacitor, Multilayer, Cera | C1, C10, C16, C17 | *STAT* C1, C10, C16, C17 | 4 | 10 | 4 | Yageo | CC0603KRX7R7BB105 | Digikey | 311-1446-1-ND | 0.066 | 0.66
46 | 100nF | Ceramic Capacitor, Multilayer, Cera | C2, C3, C4, C5, C6, C7, C8, C9, C11, C12, C13, C18, C19, C20, C21, C22 | *STAT* C2, C3, C4, C5, C6, C7, C8, C9, C11, C12, C13, C18, C19, C20, C21, C22 | 16 | 50 | 16 | Yageo | CC0603KRX7R7BB104 | Digikey | 311-1088-1-ND | 0.0238 | 1.19
47 | 27pF | Ceramic Capacitor, Multilayer, Cera | C14, C15 | *STAT* C14, C15 | 2 | 10 | 2 | Yageo | CC0603JRNPO9BN270 | Digikey | 311-1063-1-ND | 0.033 | 0.33
48 | RED | Single Color LED, Red, Water Clear, | D1, LED1 | *STAT* D1, LED1 | 2 | 4 | 2 | Wurth Electronics | 150060RS75000 | Digikey | 732-4978-1-ND | 0.15 | 0.6
49 | GREEN | Single Color LED, Bright Green, Wat | D2 | *STAT* D2 | 1 | 2 | 1 | Wurth Electronics | 150060VS75000 | Digikey | 732-4980-1-ND | 0.15 | 0.3
50 | YELLOW | Single Color LED, Yellow, Water Cle | D3, LED2 | *STAT* D3, LED2 | 2 | 4 | 2 | Wurth Electronics | 150060YS75000 | Digikey | 732-4981-1-ND | 0.15 | 0.6
51 | 10144517-081802LF | CONN RCPT 1 80POS SMD GOLD | J1 | *STAT* J1 | 1 | 2 | 1 | Amphenol ICC / FCI | 10144517-081802LF | Digikey | 609-5437-1-ND | 1.72 | 3.44
52 | 10144518-083802LF | CONN PLUG 3 80POS SMD GOLD | J2 | *STAT* J2 | 1 | 2 | 1 | Amphenol Communications Solutions | 10144518-083802LF | Digikey | 609-5455-1-ND | 1.38 | 2.76
53 | USB4105-GF-A | USB-C (USB TYPE-C) USB 2.0 Receptacle Connector 24 (16+8 Dummy) Position Surface Mount, Right Angle; Through Hole | J3 | *STAT* J3 | 1 | 2 | 1 | Global Connector Technology | USB4105-GF-A | Digikey | 2073-USB4105-GF-ACT-ND | 0.81 | 1.62
54 | 3221-10 | Connector Header Surface Mount 10 position 0.050" (1.27mm) | J4 | *STAT* J4 | 1 | 2 | 1 | CNC Tech | 3221-10-0300-00 | Digikey | 1175-1735-ND | 0.76 | 1.52
55 | MEM2052-00-195-00-A | 9 (8 + 1) Position Card Connector Secure Digital - microSD™ Surface Mount, Right Angle Gold | J5 | *STAT* J5 | 1 | 2 | 1 | GCT | MEM2052-00-195-00-A | Digikey | 2073-MEM2052-00-195-00-ACT-ND | 1.2 | 2.4
56 | Adafruit FeatherWing OLED | Adafruit FeatherWing OLED - 128x64 OLED Add-on For Feather - STEMMA QT / Qwiic | J6 | *STAT* J6 | 1 | 1 | 1 | Adafruit Industries | 4650 | Digikey | 1528-4650-ND | 14.95 | 14.95
57 | 0353630360 | Header, Molex, 2mm Pitch Sherlock Header, Single Row, Right Angle 3 Circuits, Length 3.3mm | J7 | *STAT* J7 | 1 | 2 | 1 | Molex | 35363-0360 | Digikey | WM18932-ND | 0.43 | 0.86
58 | 0353630460 | Header, Molex, 2mm Pitch Sherlock Header, Single Row, Horizontal, 4 Circuits, Length 3.3mm | J8 | *STAT* J8 | 1 | 2 | 1 | Molex | 35363-0460 | Digikey | WM18933-ND | 0.64 | 1.28
59 | DMP3056L-7 | Power Field-Effect Transistor, 4.3A | Q1 | *STAT* Q1 | 1 | 2 | 1 | Diodes | DMP3056L-7 | Digikey | DMP3056L-7DICT-ND | 0.41 | 0.82
60 | 2N7002W | Small Signal Field-Effect Transisto | Q2 | *STAT* Q2 | 1 | 2 | 1 | ON Semiconductor / Fairchild | 2N7002W | Digikey | 2N7002WCT-ND | 0.43 | 0.86
61 | MMUN2235LT1G | Small Signal Bipolar Transistor, 0. | Q3, Q4 | *STAT* Q3, Q4 | 2 | 4 | 2 | ON Semiconductor | MMUN2235LT1G | Arrow Electronics | MMUN2235LT1G | 0.1189 | 0.4756
62 | 5.1kR | Fixed Resistor, Metal Glaze/thick F | R1, R2 | *STAT* R1, R2 | 2 | 10 | 2 | Yageo | RC0603FR-075K1L | Digikey | 311-5.10KHRCT-ND | 0.019 | 0.19
63 | 1kR | Fixed Resistor, Metal Glaze/thick F | R4, R6, R8, R9, R10, R11, R12, R15 | *STAT* R4, R6, R8, R9, R10, R11, R12, R15 | 8 | 16 | 8 | Yageo | RC0603FR-071KL | Digikey | 311-1.00KHRCT-ND | 0.019 | 0.304
64 | 27.4R | Fixed Resistor, Metal Glaze/thick F | R5, R7 | *STAT* R5, R7 | 2 | 10 | 2 | Yageo | RC0603FR-0727R4L | Digikey | 311-27.4HRCT-ND | 0.02 | 0.2
65 | 10kR | Fixed Resistor, Metal Glaze/thick F | R13, R14 | *STAT* R13, R14 | 2 | 10 | 2 | Yageo | RC0603FR-0710KL | Digikey | 311-10.0KHRCT-ND | 0.019 | 0.19
66 | 270R | Fixed Resistor, Metal Glaze/thick F | R16, R19, R20 | *STAT* R16, R19, R20 | 3 | 10 | 3 | Yageo | RC0603FR-07270RL | Digikey | 311-270HRCT-ND | 0.019 | 0.19
67 | Res |  | R17, R18 | *STAT* R17, R18 | 2 | 10 | 2 | Stackpole Electronics | RMCF0603JT10K0 | Digikey | RMCF0603JT10K0CT-ND | 0.021 | 0.21
68 | PTS810 SJK 250 | Tactile Switch SPST-NO Top Actuated Surface Mount | SW1, SW2 | *STAT* SW1, SW2 | 2 | 4 | 2 | ITT C&K | PTS810SJK250SMTRLFS | Digikey | CKN10503CT-ND | 0.34 | 1.36
69 | JS202011SCQN | Slide Switch DPDT Surface Mount | SW3 | *STAT* SW3 | 1 | 2 | 1 | ITT C&K | JS202011SCQN | Digikey | 401-2002-1-ND | 0.73 | 1.46
70 | RP2040 | ARM® Cortex®-M0+ - Microcontroller IC 32-Bit Dual-Core 133MHz External Program Memory 56-QFN (7x7) | U1 | *STAT* U1 | 1 | 2 | 1 | Raspberry Pi | SC0914(13) | Digikey | 2648-SC0914(13)CT-ND | 0.7 | 1.4
71 | W25Q128JVSIQ | FLASH - NOR Memory IC 128Mbit SPI - Quad I/O, QPI, DTR 133 MHz 8-SOIC | U2 | *STAT* U2 | 1 | 2 | 1 | Winbond | W25Q128JVSIQ TR | Digikey | W25Q128JVSIQCT-ND | 1.78 | 3.56
72 | TLV757P | Linear Voltage Regulator IC Positive Fixed 1 Output 1A 6-WSON (2x2) | U3 | *STAT* U3 | 1 | 2 | 1 | Texas Instruments | TLV75733PDRVR | Digikey | 296-49281-1-ND | 0.46 | 0.92
73 | CMI-9705 | Buzzers Indicator, Internally Driven Magnetic 3 V 30mA 2.7kHz 80dB @ 3V, 10cm Surface Mount Solder Pads | U4 | *STAT* U4 | 1 | 2 | 1 | CUI Devices | CMI-9705-0380-SMT-TR | Digikey | 102-CMI-9705-0380-SMT-CT-ND | 1.77 | 3.54
74 | 74LVC1G17SE-7 | Buffer, Non-Inverting 1 Element 1 Bit per Element Push-Pull Output SOT-353 | U5 | *STAT* U5 | 1 | 2 | 1 | Diodes | 74LVC1G17SE-7 | Digikey | 74LVC1G17SE-7CT-ND | 0.27 | 0.54
75 | TCAN1044AV | 1/1 Transceiver Half CANbus TSOT-23-8 | U6 | *STAT* U6 | 1 | 2 | 1 | Texas Instruments | TCAN1057ADDFRQ1 | Digikey | 296-TCAN1057ADDFRQ1CT-ND | 0.83 | 1.66
76 | LIS3DHTR | Accelerometer X, Y, Z Axis ±2g, 4g, 8g, 16g 0.5Hz ~ 625Hz 16-LGA (3x3) | U7 | *STAT* U7 | 1 | 2 | 1 | STMicroelectronics | LIS3DHTR | Digikey | 497-10613-1-ND | 2.26 | 4.52
77 | 12.000MHZ | 12 MHz ±20ppm Crystal 18pF 50 Ohms HC-49/US | X1 | *STAT* X1 | 1 | 2 | 1 | Abracon | ABLS-12.000MHZ-B2-T | Digikey | 535-9067-1-ND | 0.24 | 0.48

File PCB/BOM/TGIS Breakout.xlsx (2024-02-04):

Line # | Name | Description | Designator | Quantity | Manufacturer 1 | Manufacturer Part Number 1 | Manufacturer Lifecycle 1 | Supplier 1 | Supplier Part Number 1 | Supplier Unit Price 1 | Supplier Subtotal 1
1 | 10144518-081802LF | CONN PLUG 1 80POS SMD GOLD | J1 | 1 | Amphenol Communications Solutions | 10144518-081802LF | Unknown | Digikey | 609-5453-1-ND | 1.89 | 1.89
2 | PREC012DAAN-RC | Connector Header Through Hole 24 position 0.100" (2.54mm) | J2, J3 | 2 | Sullins | PREC040DAAN-RC | Volume Production | Digikey | S2012EC-12-ND | 0.38 | 0.76
3 | 1877285-2 |  | J4, J5 | 2 | TE Connectivity | 1877285-2 | Volume Production | Digikey | A99845-ND | 0.31 | 0.62

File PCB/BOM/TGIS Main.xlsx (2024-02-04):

Line # | Name | Description | Designator | Quantity | Value | Footprint | Manufacturer 1 | Manufacturer Part Number 1 | Manufacturer Lifecycle 1 | Supplier 1 | Supplier Part Number 1 | Supplier Unit Price 1 | Supplier Subtotal 1
1 | Cap |  | C1, C2 | 2 | 100nF | CAPC0603 | Samsung | CL10B104KB8NNNC | Volume Production | Mouser | 187-CL10B104KB8NNNC | 0.013 | 0.13
2 | 3V0 | DIODE ZENER 3.0V 500MW SOD123 | D1 | 1 |  | SOD3715X135N | Diodes | BZT52C3V0-7-F | Volume Production | Digikey | BZT52C3V0-FDICT-ND | 0.21 | 0.21
3 | TN805 | SCR 600 V 8 A Standard Recovery Surface Mount DPAK | D2, D4 | 2 |  | DPAK_TN | STMicroelectronics | TN805-600B-TR | Volume Production | Digikey | 497-6769-1-ND | 1.62 | 3.24
4 | 4V7 | DIODE ZENER 4.7V 500MW SOD123 | D3 | 1 |  | SOD3715X135N | Diodes | BZT52C4V7-13-F | Volume Production | Digikey | BZT52C4V7-13-FDICT-ND | 0.21 | 0.21
5 | Fuse Holder | Fuse Holder 30 A 500V 1 Circuit Blade Through Hole | F1, F2 | 2 |  | FUSE_3568 | Keystone Electronics | 3568 | Volume Production | Future Electronics | 4264032 | 0.98 | 1.96
6 | 10144517-081802LF | CONN RCPT 1 80POS SMD GOLD | J1 | 1 |  | AMPHENOL_10144517-081802LF | Amphenol ICC / FCI | 10144517-081802LF | Unknown | Digikey | 609-5437-1-ND | 1.72 | 1.72
7 | 1877285-2 |  | J2, J3 | 2 |  | TE_1877285-2 | TE Connectivity | 1877285-2 | Volume Production | Digikey | A99845-ND | 0.31 | 0.62
9 | AONR21321 | P-Channel 30 V 24A (Tc) 4.1W (Ta), 24W (Tc) Surface Mount 8-DFN-EP (3x3) | Q1, Q2 | 2 |  | TRANS_AONR21321 | Alpha & Omega Semiconductor | AONR21321 | Volume Production | Digikey | 785-1797-1-ND | 0.44 | 0.88
10 | Res |  | R1, R2 | 2 | 3k3 | RES0603 | Stackpole Electronics | RMCF0603FT3K30 | Volume Production | Mouser | 708-RMCF0603FT3K30 | 0.009 | 0.09
11 | Res |  | R3, R4 | 2 | 1k | RES0603 | Stackpole Electronics | RMCF0603FT1K00 | Volume Production | Mouser | 708-RMCF0603FT1K00 | 0.009 | 0.09

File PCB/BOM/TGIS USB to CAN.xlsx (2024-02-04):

Line # | Name | Description | Designator | Quantity | Value | Footprint | Manufacturer 1 | Manufacturer Part Number 1 | Manufacturer Lifecycle 1 | Supplier 1 | Supplier Part Number 1 | Supplier Unit Price 1 | Supplier Subtotal 1
1 | Cap |  | C1 | 1 | 4.7n | CAPC0603 | KEMET | C0603C472K4RECAUTO | Volume Production | Digikey | 399-17879-1-ND | 0.15 | 0.3
2 | Cap |  | C2, C11, C24, C25 | 4 | 1u | CAPC0603 | KEMET | C0603C105K4RAC7411 | Volume Production | Digikey | 399-C0603C105K4RAC7411CT-ND | 0.073 | 0.73
3 | Cap |  | C3, C4, C5, C6, C7, C8, C9, C10, C12, C13, C14, C17, C18 | 13 | 100n | CAPC0603 | Samsung | CL10B104KB8NNNC | Volume Production | Digikey | 1276-1000-1-ND | 0.026 | 0.676
 | Cap |  | C15, C16 | 2 | 27p | CAPC0603 | Kyocera AVX | 06035C270JAT2A | Volume Production | Digikey | 478-11825-1-ND | 0.22 | 0.88
7 | FTSH-110 | Connector Header Surface Mount 20 position 0.050" (1.27mm) | J1 | 1 |  | SAMTEC_FTSH-110-01-L-DV-007 | Samtec | FTSH-110-01-L-DV-007-K | Volume Production | Digikey | SAM9456-ND | 3 | 6
8 | 10144517-081802LF | CONN RCPT 1 80POS SMD GOLD | J2 | 1 |  | AMPHENOL_10144517-081802LF | Amphenol ICC / FCI | 10144517-081802LF | Unknown | Digikey | 609-5437-1-ND | 1.72 | 3.44
9 | 10144518-083802LF | CONN PLUG 3 80POS SMD GOLD | J3 | 1 |  | AMPHENOL_10144518-083802LF | Amphenol Communications Solutions | 10144518-083802LF | Volume Production | Digikey | 609-5455-1-ND | 1.38 | 2.76
10 | USB4120-03 | USB-C (USB TYPE-C) USB 2.0 Receptacle Connector 24 (16+8 Dummy) Position Surface Mount, Through Hole | J4 | 1 |  | GCT_USB4120-03-C_REVA | Global Connector Technology | USB4120-03-C | Volume Production | Digikey | 2073-USB4120-03-CCT-ND | 0.92 | 1.84
11 | 3221-10 | Connector Header Surface Mount 10 position 0.050" (1.27mm) | J6 | 1 |  | CNC_3221-10-0300-00 | CNC Tech | 3221-10-0300-00 | Unknown | Digikey | 1175-1735-ND | 0.76 | 1.52
12 | RJHSE-3381 | Jack Modular Connector 8p8c (RJ45, Ethernet) Vertical Shielded | J7 | 1 |  | AMPHENOL_RJHSE3381 | Amphenol Communications Solutions | RJHSE-3381 | Unknown | Digikey | RJHSE-3381-ND | 2.85 | 5.7
 | PH2RA-28-UA | Connector Header Through Hole, Right Angle 28 position 0.100" (2.54mm) | J8 | 1 |  | PH2RA-28-UA |  |  |  | Digikey | 2057-PH2RA-28-UA-ND
15 | Res |  | R1, R2 | 2 | 5k1 | RES0603 | Yageo | RT0603BRE075KL | Volume Production | Digikey | 13-RT0603BRE075KLCT-ND | 0.16 | 0.64
16 | Res |  | R3, R6 | 2 | 220 | RES0603 | Stackpole Electronics | RMCF0603FT220R | Volume Production | Digikey | RMCF0603FT220RCT-ND | 0.015 | 0.15
17 | Res |  | R4, R5 | 2 | 60.4 | RES0603 | Stackpole Electronics | RMCF0603FT60R4 | Volume Production | Digikey | RMCF0603FT60R4CT-ND | 0.015 | 0.15
19 | Res |  | R8, R10, R12, R17, R18 | 5 | 1k | RES0603 | Stackpole Electronics | RMCF0603FT1K00 | Volume Production | Digikey | RMCF0603FT1K00CT-ND | 0.015 | 0.15
20 | Res |  | R9, R11 | 2 | 27.4 | RES0603 | Stackpole Electronics | RMCF0603JT10K0 | Volume Production | Digikey | RMCF0603JT10K0CT-ND | 0.021 | 0.21
22 | PTS810 SJK 250 | Tactile Switch SPST-NO Top Actuated Surface Mount | SW1, SW2 | 2 |  | SW_PTS810_SJM_250_SMTR_LFS | ITT C&K | PTS810SJK250SMTRLFS | Volume Production | Digikey | CKN10503CT-ND | 0.34 | 1.36
23 | JS202011SCQN | Slide Switch DPDT Surface Mount | SW3 | 1 |  | SW_JS202011SCQN | ITT C&K | JS202011SCQN | Volume Production | Digikey | 401-2002-1-ND | 0.64 | 1.28
25 | RP2040 | ARM® Cortex®-M0+ - Microcontroller IC 32-Bit Dual-Core 133MHz External Program Memory 56-QFN (7x7) | U1 | 1 |  | QFN40P700X700X90-57N | Raspberry Pi | SC0914(13) | Unknown | Digikey | 2648-SC0914(13)CT-ND | 0.7 | 1.4
26 | W25Q128JVSIQ | FLASH - NOR Memory IC 128Mbit SPI - Quad I/O, QPI, DTR 133 MHz 8-SOIC | U2 | 1 |  | SOIC127P790X216-8N | Winbond | W25Q128JVSIQ TR | Volume Production | Digikey | W25Q128JVSIQCT-ND | 1.72 | 3.44
27 | TCAN1044AV | 1/1 Transceiver Half CANbus TSOT-23-8 | U3 | 1 |  | SOT65P280X110-8N | Texas Instruments | TCAN1057ADDFRQ1 | Volume Production | Digikey | 296-TCAN1057ADDFRQ1CT-ND | 0.83 | 1.66
28 | TLV757P | Linear Voltage Regulator IC Positive Fixed 1 Output 1A 6-WSON (2x2) | U5 | 1 |  | VREG_TLV75733PDRVR | Texas Instruments | TLV75733PDRVR | Volume Production | Digikey | 296-49281-1-ND | 0.46 | 0.92
29 | 12.000MHZ | 12 MHz ±20ppm Crystal 18pF 50 Ohms HC-49/US | X1 | 1 |  | ABLS-12.000MHZ | Abracon | ABLS-12.000MHZ-B2-T | Unknown | Digikey | 535-9067-1-ND | 0.24 | 0.48

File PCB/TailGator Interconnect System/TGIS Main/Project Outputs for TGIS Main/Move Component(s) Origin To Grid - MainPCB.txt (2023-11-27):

Move Component(s) Origin to Grid
Filename     : C:\Users\molyo\AppData\Local\Temp\History\MainPCB.PcbDoc
Date         : 11/15/2023
Time         : 4:03:56 PM
Time Elapsed : 00:00:00

    Component J6-FTSH-110 (2580mil,600mil) on Top Layer - Component origin is already ON grid. - Component pads are OFF grid. No action taken.
    Component J5-RJHSE-3381 (1000mil,920mil) on Top Layer - Component origin is already ON grid. - Component pads are OFF grid. No action taken.
    Component J2-USB4115-03-C (900mil,600mil) on Top Layer - Component origin is already ON grid. - Component pads are OFF grid. No action taken.
    Small Component J4-1877285-2 (1600mil,1080mil) on Top Layer - Component origin is already ON grid. - Component pads are OFF grid. No action taken.
    Small Component J3-1877285-2 (2120mil,1080mil) on Top Layer - Component origin is already ON grid. - Component pads are OFF grid. No action taken.
    SOIC Component J1-10144517-061802LF (1700mil,600mil) on Bottom Layer - Component origin is already ON grid. - Component pads are OFF grid. No action taken.
count : 6

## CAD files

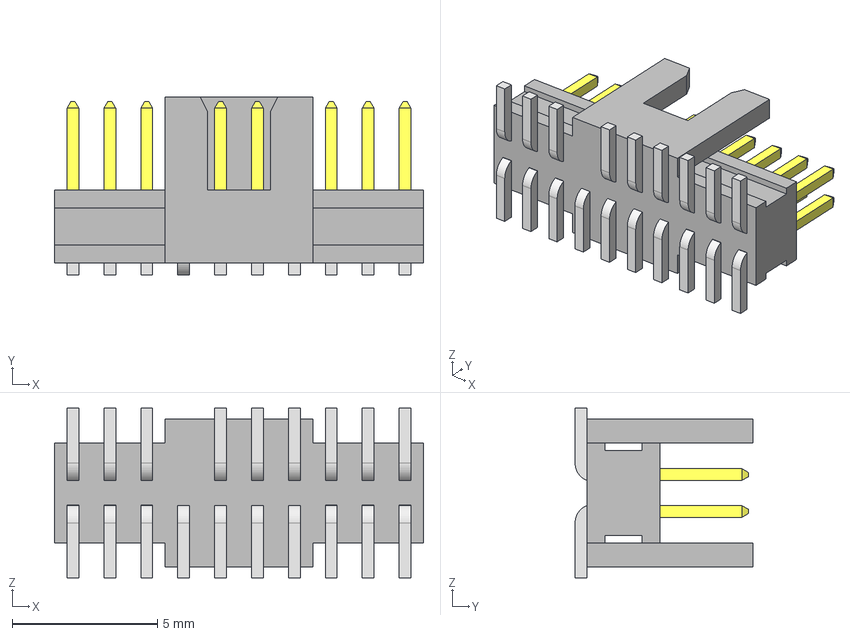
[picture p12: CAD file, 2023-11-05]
PCB/3D Models/SamTec/FTSH-110-01-L-DV-007-K.stp
12.7 x 6.12 x 5.84 mm
FTSH-110-01-L-DV-007-K_pins2
FTSH-110-01-L-DV-007-K_pins1
FTSH-110-01-L-DV-007-K_body

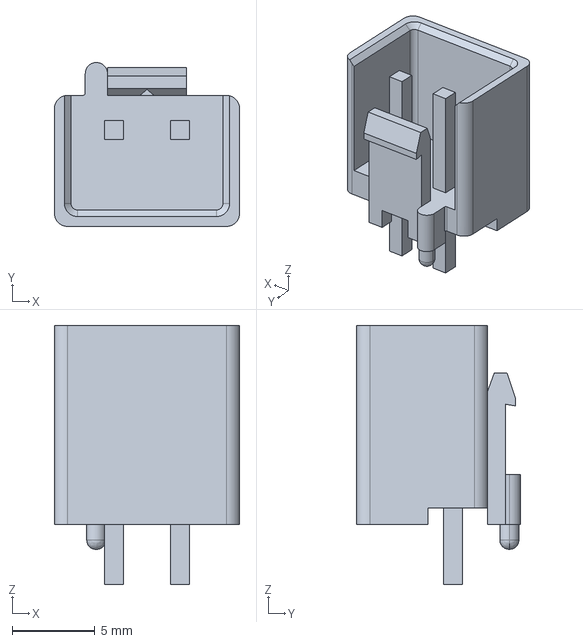
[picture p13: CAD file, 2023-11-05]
PCB/3D Models/TE Connectivity/c-1877285-2-c-3d.stp
11.2 x 9.89 x 15.6 mm

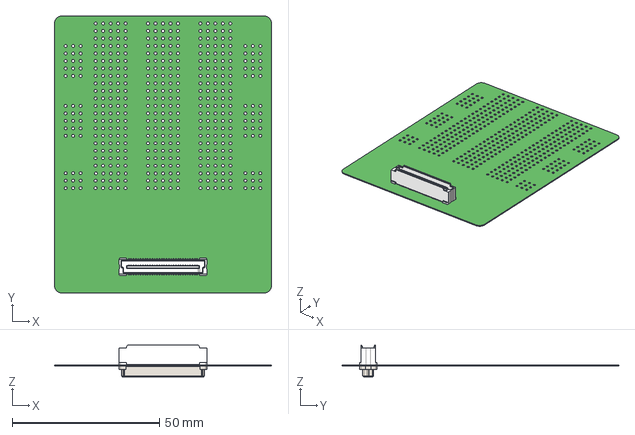
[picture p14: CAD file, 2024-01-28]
PCB/TailGator Interconnect System/TGIS System Status/Project Outputs for TGIS USB to CAN/TGIS USB to CAN/ExportSTEP/Protoboard.step
73.7 x 94.0 x 10.7 mm

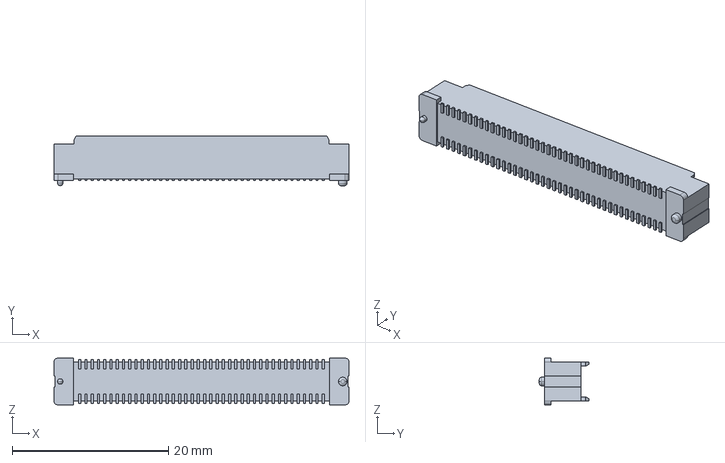
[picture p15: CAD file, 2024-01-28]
PCB/3D Models/Amphenol/10144518-082802LF.STEP
37.8 x 6.35 x 6.00 mm

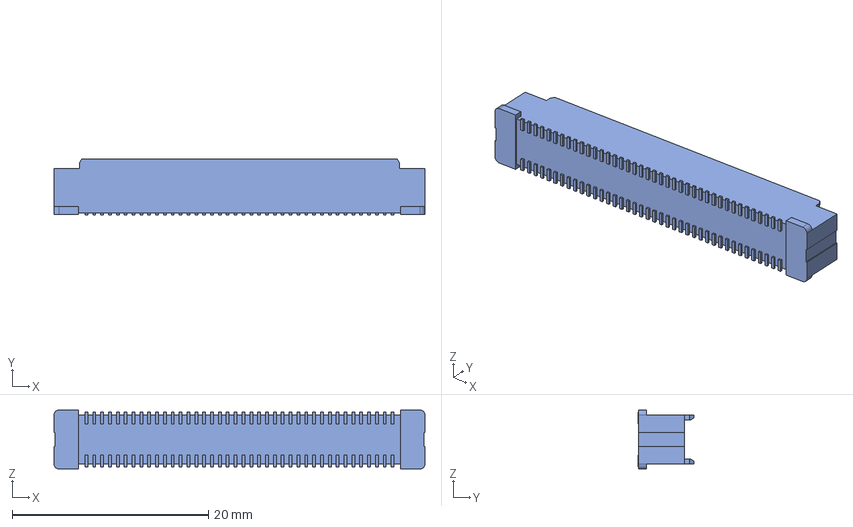
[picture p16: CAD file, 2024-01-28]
PCB/3D Models/Amphenol/Pegs Removed/10144518-082802LF NoPeg.step
37.8 x 5.70 x 6.00 mm

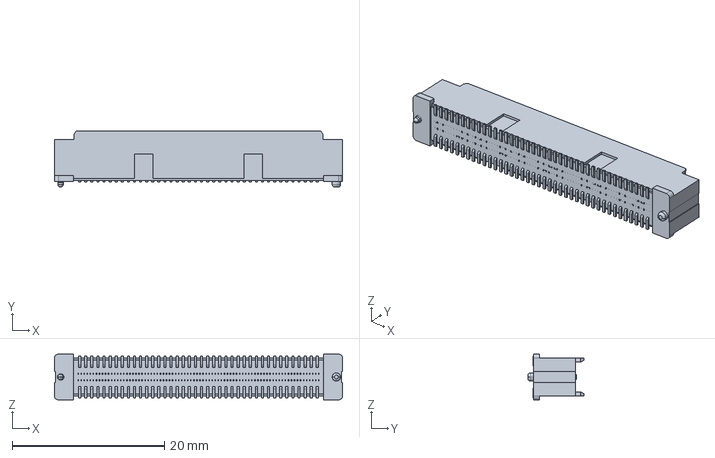
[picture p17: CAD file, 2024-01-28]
PCB/3D Models/Amphenol/10144518-083802LF.STEP
37.8 x 7.35 x 6.00 mm

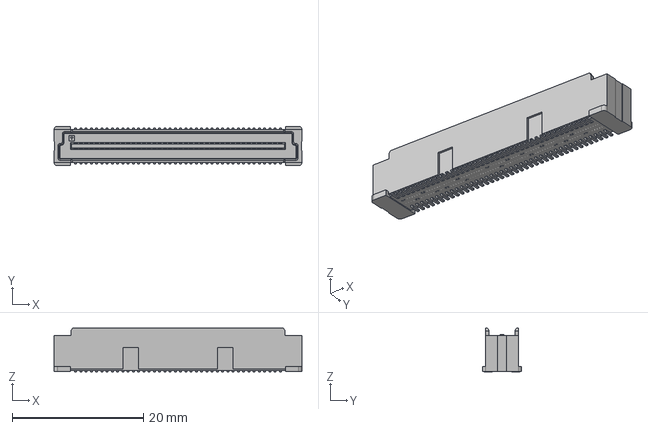
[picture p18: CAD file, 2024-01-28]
PCB/3D Models/Amphenol/Pegs Removed/10144518-083802LF NoPeg.step
37.8 x 6.00 x 6.70 mm

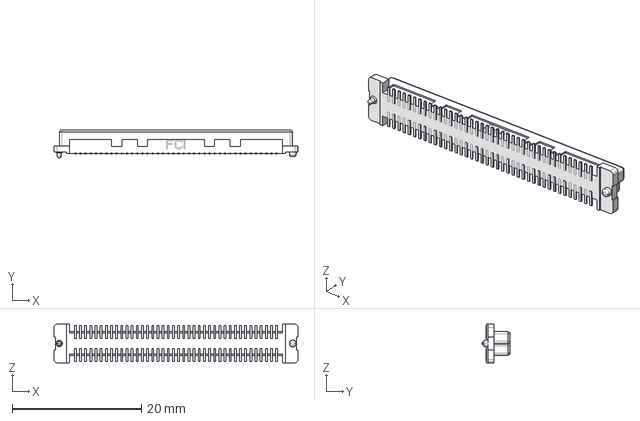
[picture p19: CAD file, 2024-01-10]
PCB/3D Models/Amphenol/10144517-081802LF.STEP
37.8 x 4.35 x 6.00 mm

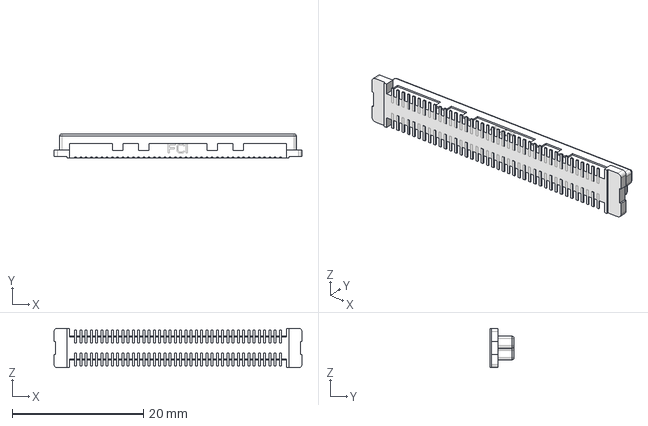
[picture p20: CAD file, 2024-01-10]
PCB/3D Models/Amphenol/Pegs Removed/10144517-081802LF NoPeg.step
37.8 x 3.70 x 6.00 mm

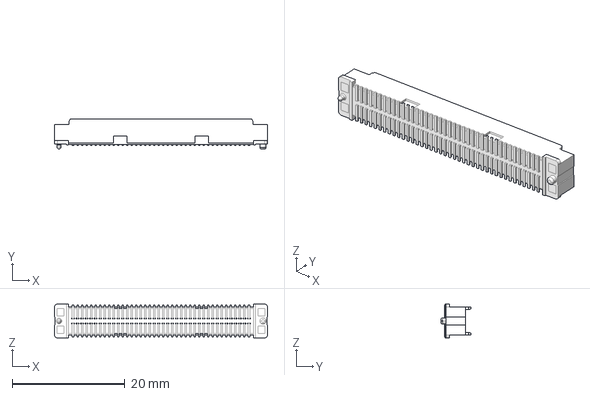
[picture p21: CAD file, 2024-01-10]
PCB/3D Models/Amphenol/10144518-081802LF.STEP
37.8 x 5.35 x 6.00 mm

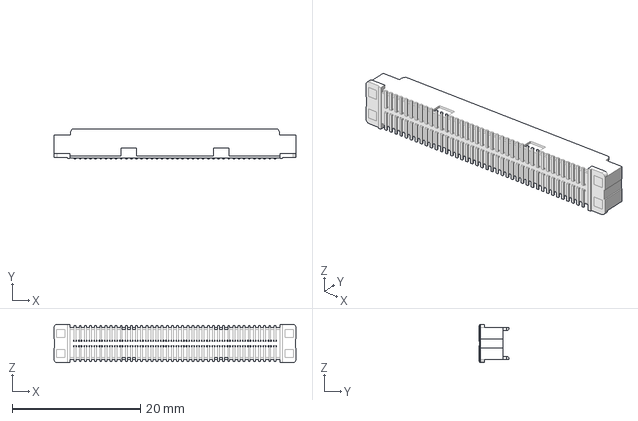
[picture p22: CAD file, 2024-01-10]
PCB/3D Models/Amphenol/Pegs Removed/10144518-081802LF NoPeg.step
37.8 x 4.70 x 6.00 mm

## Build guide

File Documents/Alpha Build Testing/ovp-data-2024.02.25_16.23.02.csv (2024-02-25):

Input Voltage (V) | 3.3V Rail Voltage (V) | 3.3V OVP Circuit Voltage (V)
2.7 | 2.168 | 0.07
2.9 | 2.353 | 0.115
3.1 | 2.538 | 0.177
3.3 | 2.728 | 0.255
3.5 | 2.921 | 0.343
3.7 | 3.111 | 0.45
3.9 | 3.3 | 0.552
4.1 | 0.794 | 0.832
4.3 | 0.823 | 0.816
4.5 | 0.838 | 0.811

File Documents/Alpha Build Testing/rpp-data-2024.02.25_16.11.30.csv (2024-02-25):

Input Voltage (V) | 3.3V Rail Voltage (V)
2 | 0.015
4 | 0.014
6 | 0.014
8 | 0.013
10 | 0.013
12 | 0.011
14 | 0.01
16 | 0.009
18 | 0.006
20 | 0.004
22 | -0.002
24 | -0.008

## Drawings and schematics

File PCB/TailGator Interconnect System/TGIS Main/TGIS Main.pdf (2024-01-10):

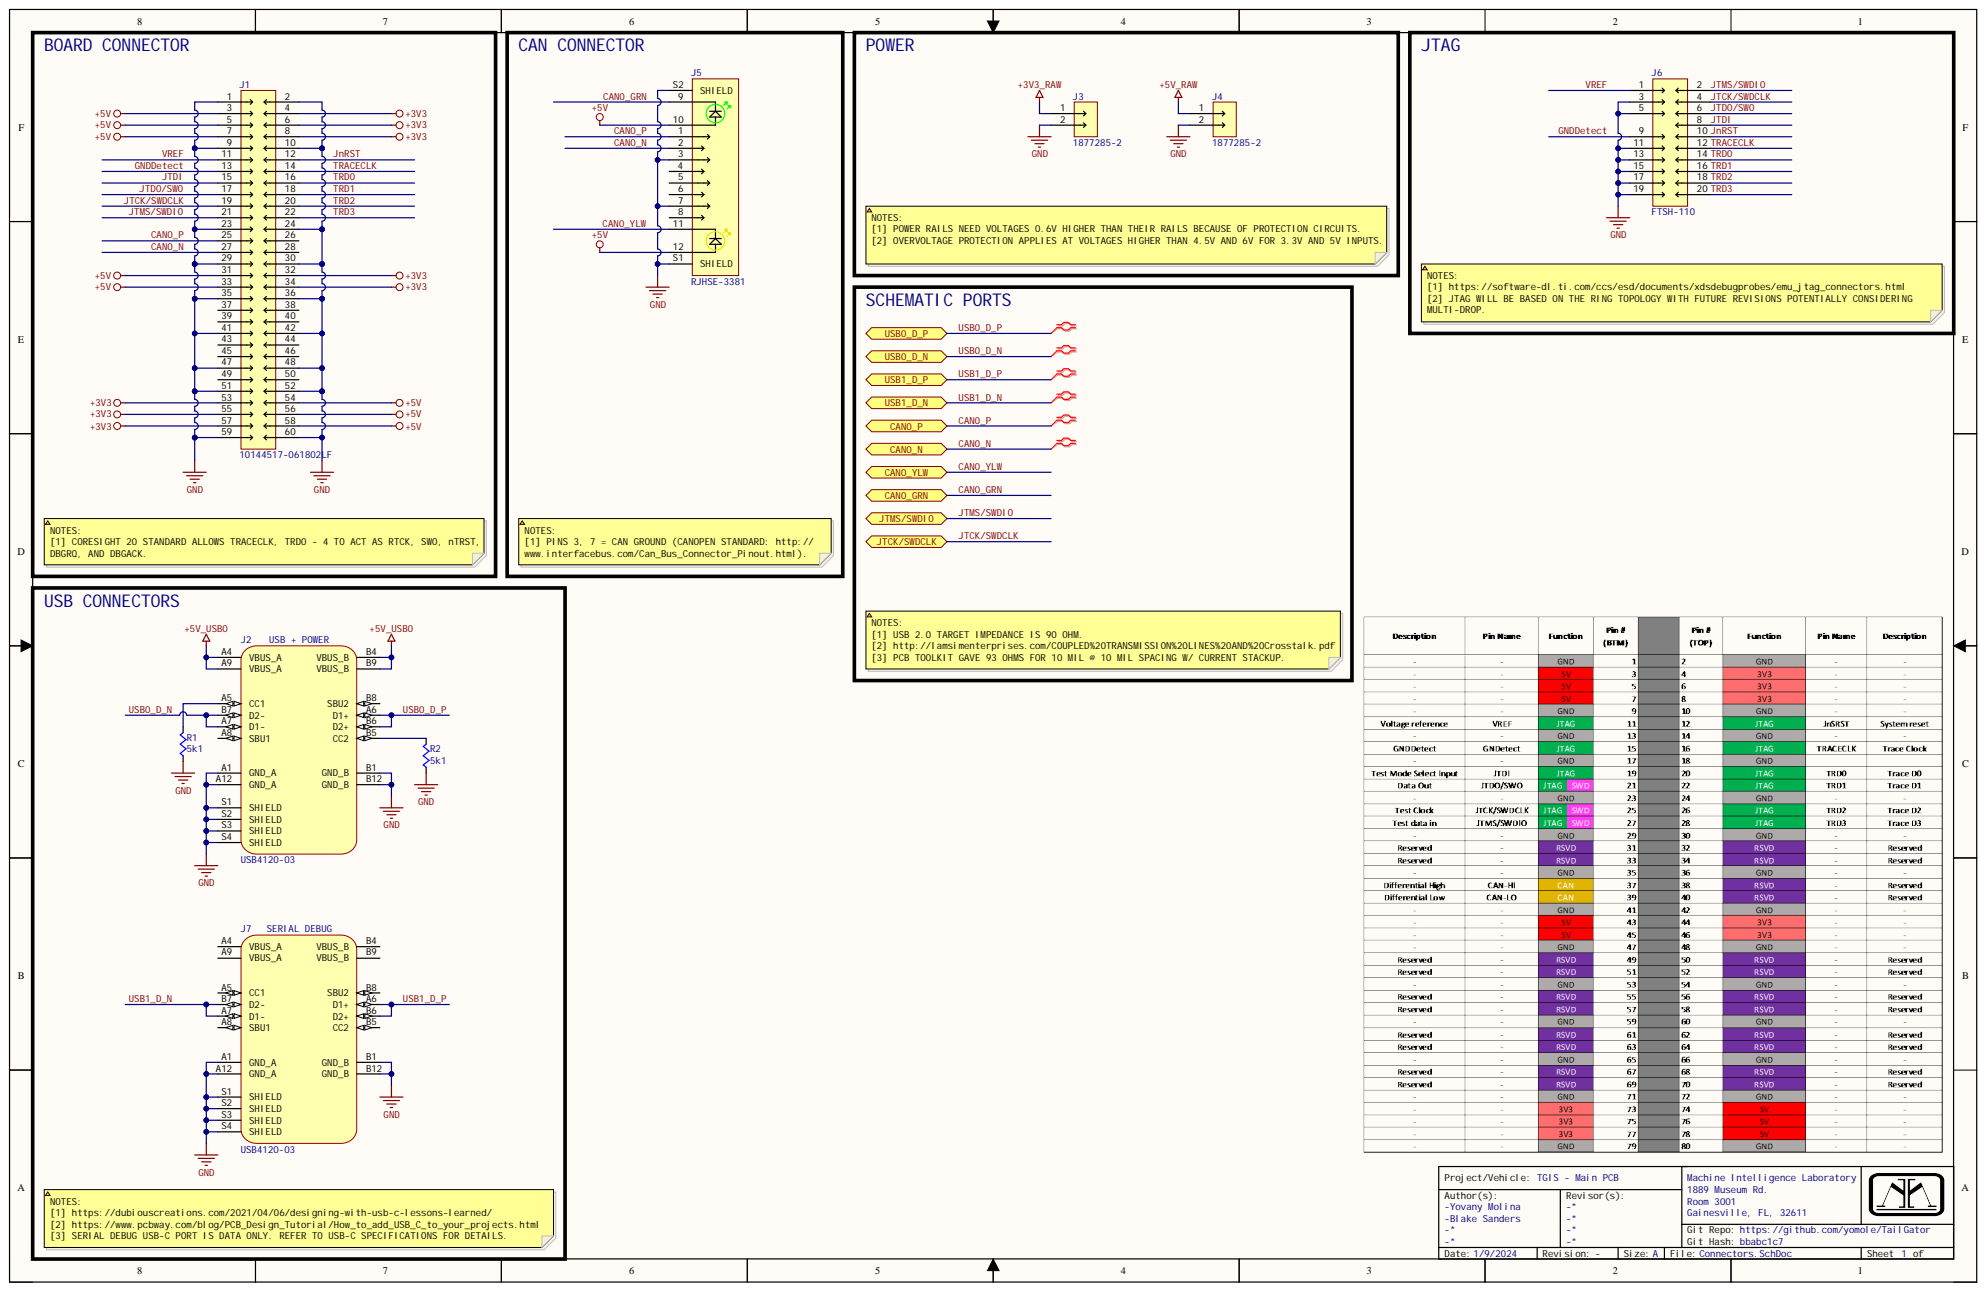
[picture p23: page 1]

J1 | | CAN CONNECTOR J5 | POWER +3V3_RAW +5V_RAW J3 J4 NOTES: [1] POWER RAILS NEED VOLTAGES 0.6V HIGHER THAN THEIR RAILS BECAUSE OF PROTECTION CIRCUITS. [2] OVERVOLTAGE PROTECTION APPLIES AT VOLTAGES HIGHER THAN 4.5V AND 6V FOR 3.3V AND 5V INPUTS. | JTAG J6 NOTES: MULTI-DROP.

[1] https://software-dl.ti.com/ccs/esd/documents/xdsdebugprobes/emu_jtag_connectors.html
[2] JTAG WILL BE BASED ON THE RING TOPOLOGY WITH FUTURE REVISIONS POTENTIALLY CONSIDERING

NOTES:
[1] CORESIGHT 20 STANDARD ALLOWS TRACECLK, TRD0 - 4 TO ACT AS RTCK, SWO, nTRST,
DBGRQ, AND DBGACK.

[1] PINS 3, 7 = CAN GROUND (CANOPEN STANDARD: http://
www.interfacebus.com/Can_Bus_Connector_Pinout.html).

[1] USB 2.0 TARGET IMPEDANCE IS 90 OHM.
[2] http://lamsimenterprises.com/COUPLED%20TRANSMISSION%20LINES%20AND%20Crosstalk.pdf
[3] PCB TOOLKIT GAVE 93 OHMS FOR 10 MIL @ 10 MIL SPACING W/ CURRENT STACKUP.

Project/Vehicle: TGIS - Main PCB | Machine Intelligence Laboratory 1889 Museum Rd. Room 3001 Gainesville, FL, 32611
Author(s): -Yovany Molina -Blake Sanders -* -* | Revisor(s): -* -* -* -*

[1] https://dubiouscreations.com/2021/04/06/designing-with-usb-c-lessons-learned/
[2] https://www.pcbway.com/blog/PCB_Design_Tutorial/How_to_add_USB_C_to_your_projects.html
[3] SERIAL DEBUG USB-C PORT IS DATA ONLY. REFER TO USB-C SPECIFICATIONS FOR DETAILS.

https://github.com/yomole/TailGator

Date: 1/9/2024 | Revision: - | Size: A | File: Connectors.SchDoc | Sheet 1 of

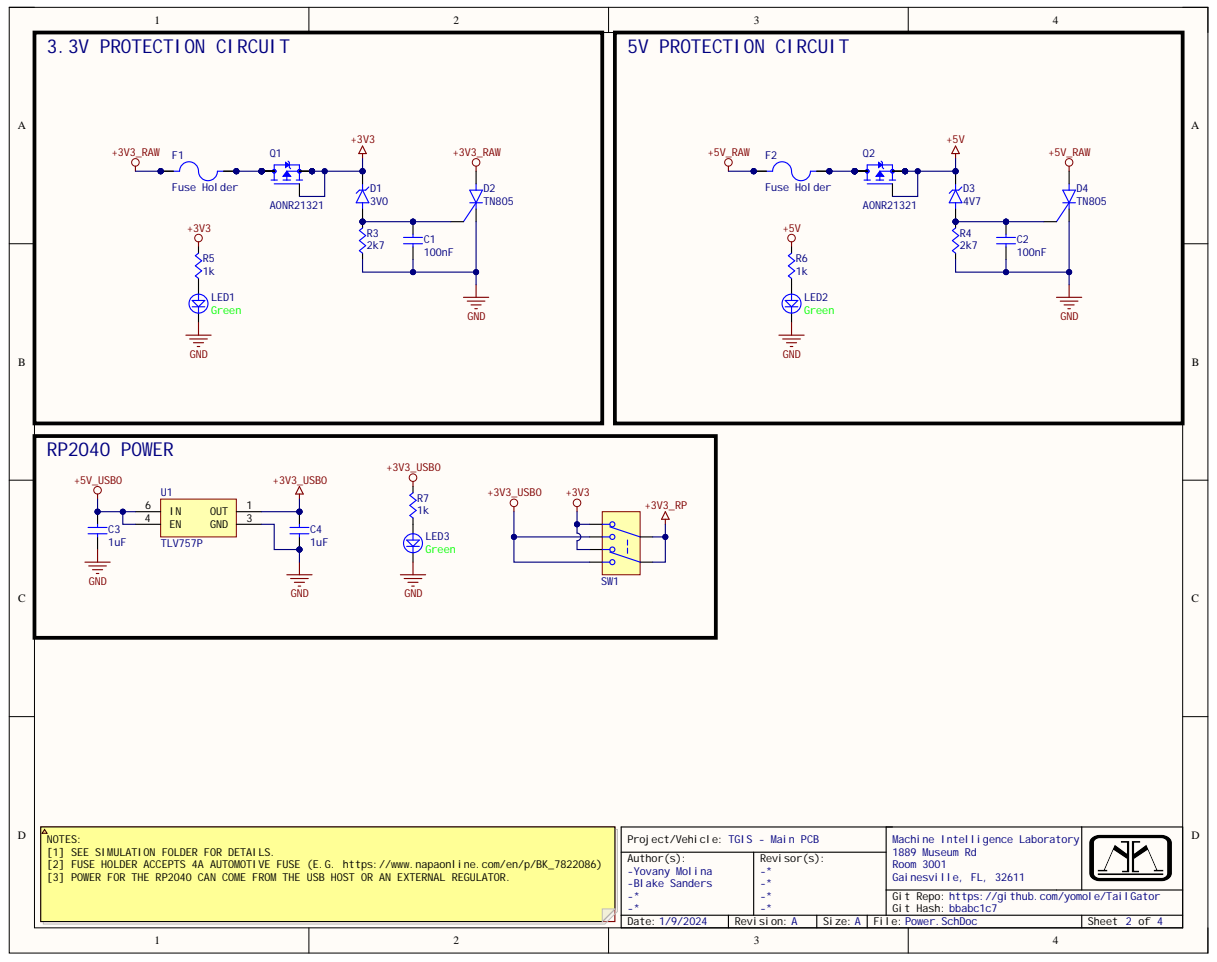
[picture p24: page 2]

NOTES: [1] SEE SIMULATION FOLDER FOR DETAILS. [2] FUSE HOLDER ACCEPTS 4A AUTOMOTIVE FUSE (E.G. https://www.napaonline.com/en/p/BK_7822086) PLACE NOTES BOX HERE [3] POWER FOR THE RP2040 CAN COME FROM THE USB HOST OR AN EXTERNAL REGULATOR. | Project/Vehicle: TGIS - Main PCB | Machine Intelligence Laboratory 1889 Museum Rd Room 3001 Gainesville, FL, 32611

Author(s): -Yovany Molina -Blake Sanders * | Revisor(s): -*

https://github.com/yomole/TailGator

Date:1/9/2024 | Revision: A | Size:A | File:Power.SchDoc | Sheet 2 of 4

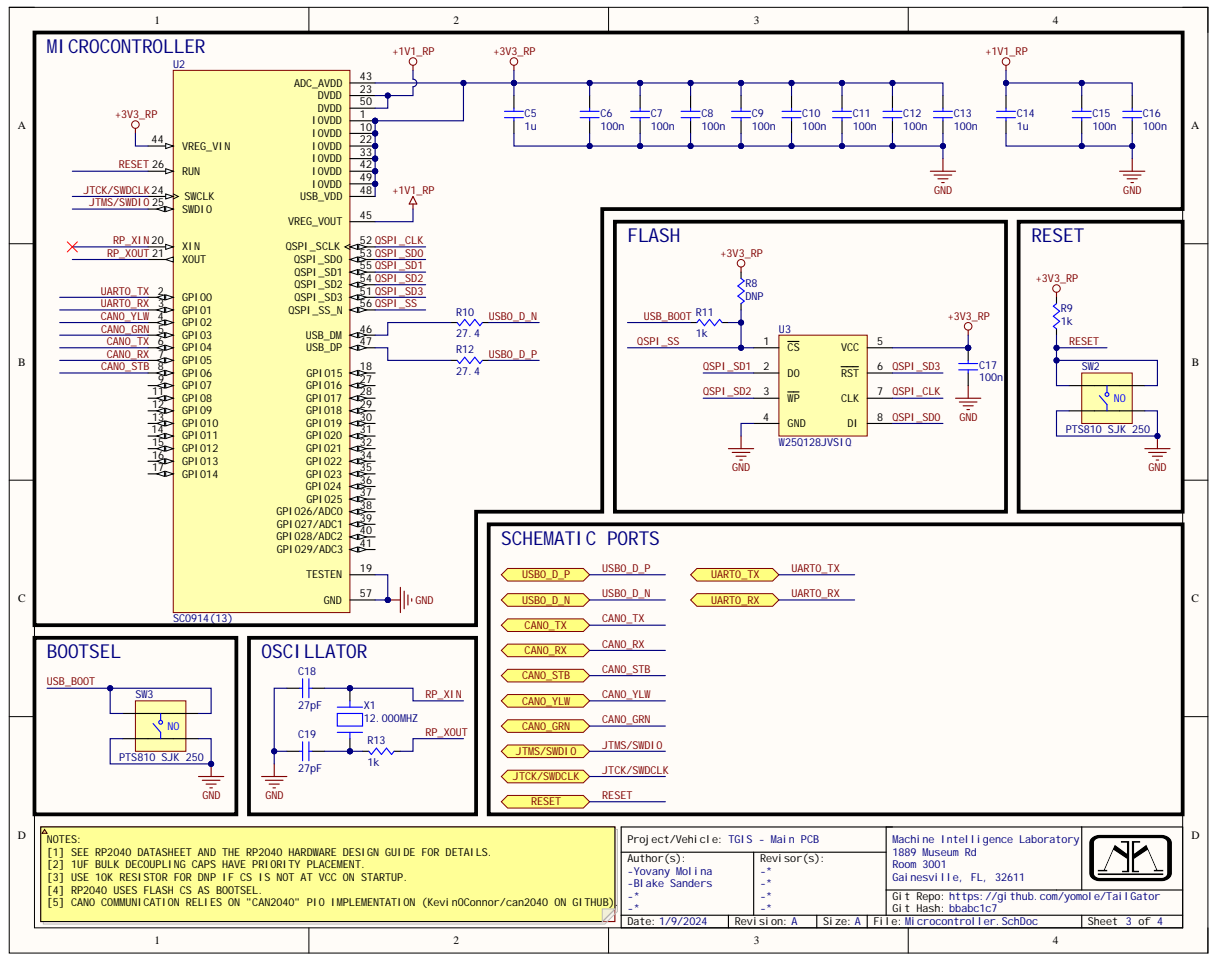
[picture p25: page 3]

NOTES: [1] SEE RP2040 DATASHEET AND THE RP2040 HARDWARE DESIGN GUIDE FOR DETAILS. [2] 1UF BULK DECOUPLING CAPS HAVE PRIORITY PLACEMENT. PLACE NOTES BOX HERE [3] USE 10K RESISTOR FOR DNP IF CS IS NOT AT VCC ON STARTUP. [4] RP2040 USES FLASH CS AS BOOTSEL. [5] CAN0 COMMUNICATION RELIES ON "CAN2040" PIO IMPLEMENTATION (KevinOConnor/can2040 ON GITHUB). | Project/Vehicle: TGIS - Main PCB | Machine Intelligence Laboratory 1889 Museum Rd Room 3001 Gainesville, FL, 32611

Author(s): -Yovany Molina | Revisor(s): -*

Date:1/9/2024 | Revision: A | Size:A | File:Microcontroller.SchDoc | Sheet 3 of 4

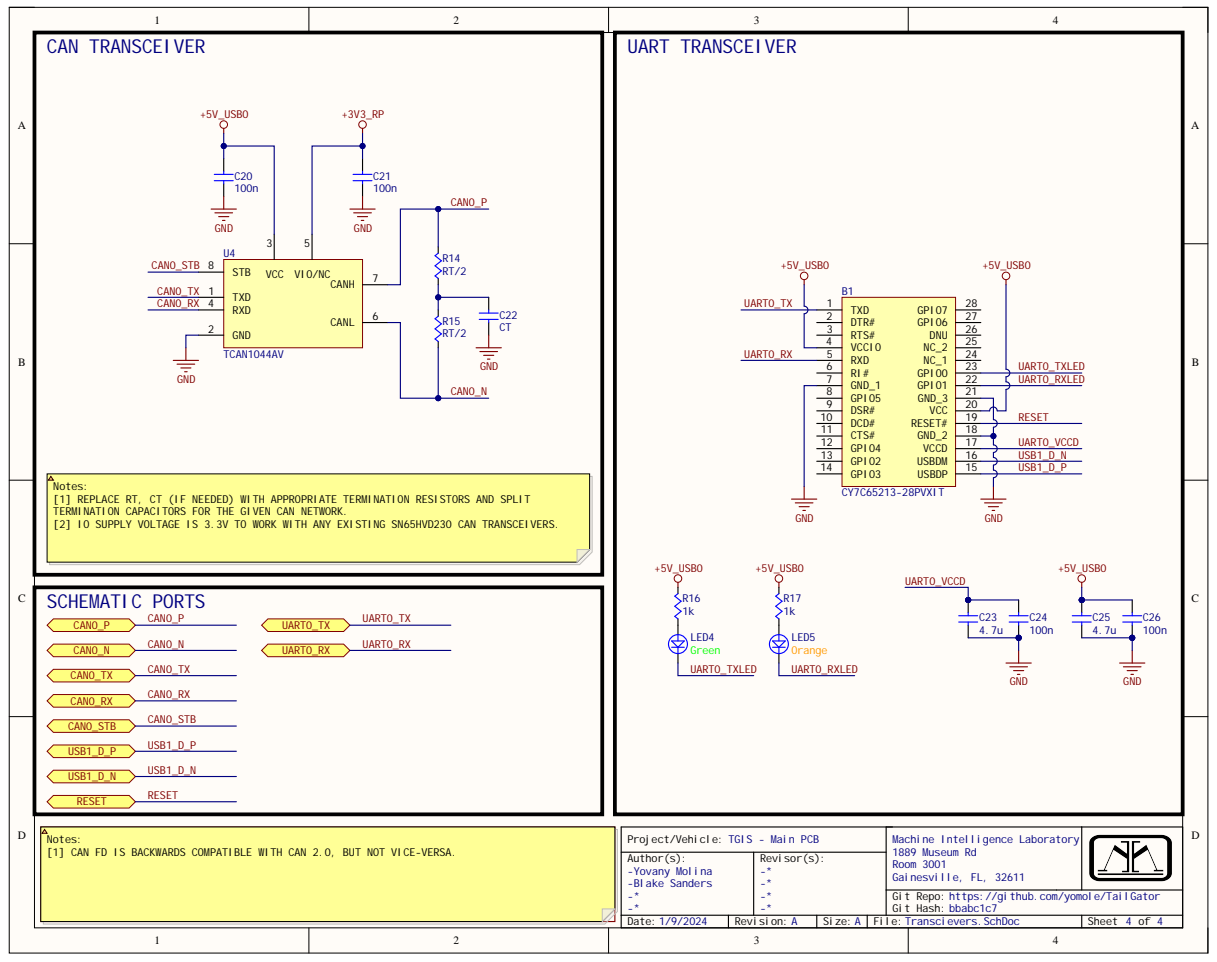
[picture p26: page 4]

Notes:
[1] REPLACE RT, CT (IF NEEDED) WITH APPROPRIATE TERMINATION RESISTORS AND SPLIT
TERMINATION CAPACITORS FOR THE GIVEN CAN NETWORK.
[2] IO SUPPLY VOLTAGE IS 3.3V TO WORK WITH ANY EXISTING SN65HVD230 CAN TRANSCEIVERS.

Notes: [1] CAN FD IS BACKWARDS COMPATIBLE WITH CAN 2.0, BUT NOT VICE-VERSA. PLACE NOTES BOX HERE | Project/Vehicle: TGIS - Main PCB | Machine Intelligence Laboratory 1889 Museum Rd Room 3001 Gainesville, FL, 32611

Author(s): -Yovany Molina | Revisor(s): -*

Date:1/9/2024 | Revision: A | Size:A | File:Transcievers.SchDoc | Sheet 4 of 4

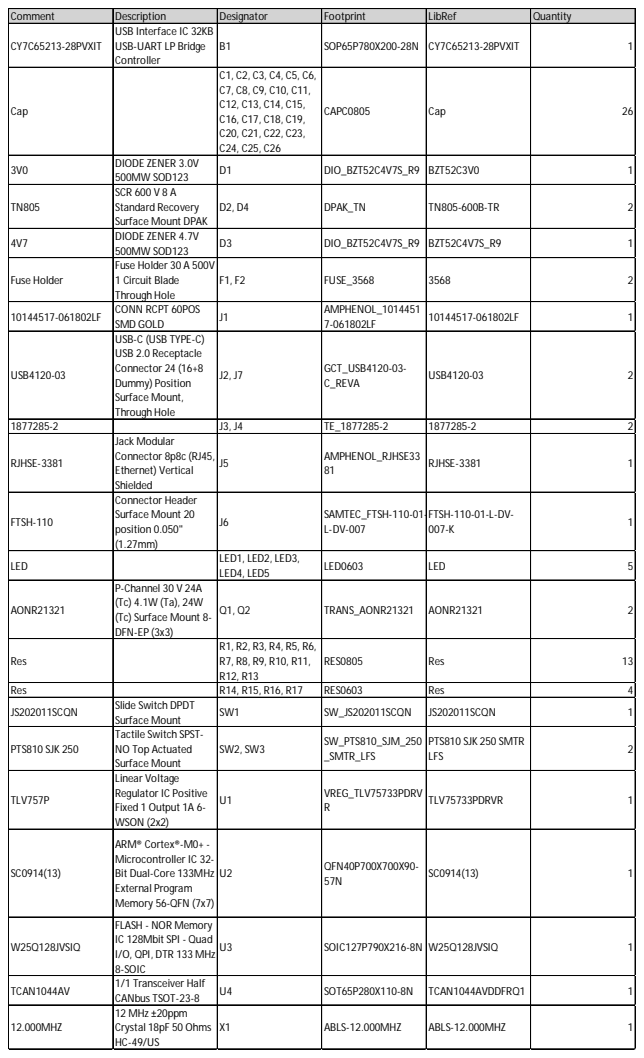
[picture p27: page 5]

Comment | Description | Designator | Footprint | LibRef | Quantity
CY7C65213-28PVXIT | USB Interface IC 32KB USB-UART LP Bridge Controller | B1 | SOP65P780X200-28N | CY7C65213-28PVXIT | 1

Cap | | C1, C2, C3, C4, C5, C6, C7, C8, C9, C10, C11, C12, C13, C14, C15, C16, C17, C18, C19, C20, C21, C22, C23, C24, C25, C26 | CAPC0805 | Cap | 26

3V0 | DIODE ZENER 3.0V 500MW SOD123 | D1 | DIO_BZT52C4V7S_R9 | BZT52C3V0 | 1

TN805 | SCR 600 V 8 A Standard Recovery Surface Mount DPAK | D2, D4 | DPAK_TN | TN805-600B-TR | 2

4V7 | DIODE ZENER 4.7V 500MW SOD123 | D3 | DIO_BZT52C4V7S_R9 | BZT52C4V7S_R9 | 1

Fuse Holder | Fuse Holder 30 A 500V 1 Circuit Blade Through Hole | F1, F2 | FUSE_3568 | 3568 | 2

10144517-061802LF | CONN RCPT 60POS SMD GOLD | J1 | AMPHENOL_1014451 7-061802LF | 10144517-061802LF | 1

USB4120-03 | USB-C (USB TYPE-C) USB 2.0 Receptacle Connector 24 (16+8 Dummy) Position Surface Mount, Through Hole | J2, J7 | GCT_USB4120-03-C_REVA | USB4120-03 | 2

1877285-2 | | J3, J4 | TE_1877285-2 | 1877285-2 | 2
RJHSE-3381 | Jack Modular Connector 8p8c (RJ45, Ethernet) Vertical Shielded | J5 | AMPHENOL_RJHSE33 81 | RJHSE-3381 | 1
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

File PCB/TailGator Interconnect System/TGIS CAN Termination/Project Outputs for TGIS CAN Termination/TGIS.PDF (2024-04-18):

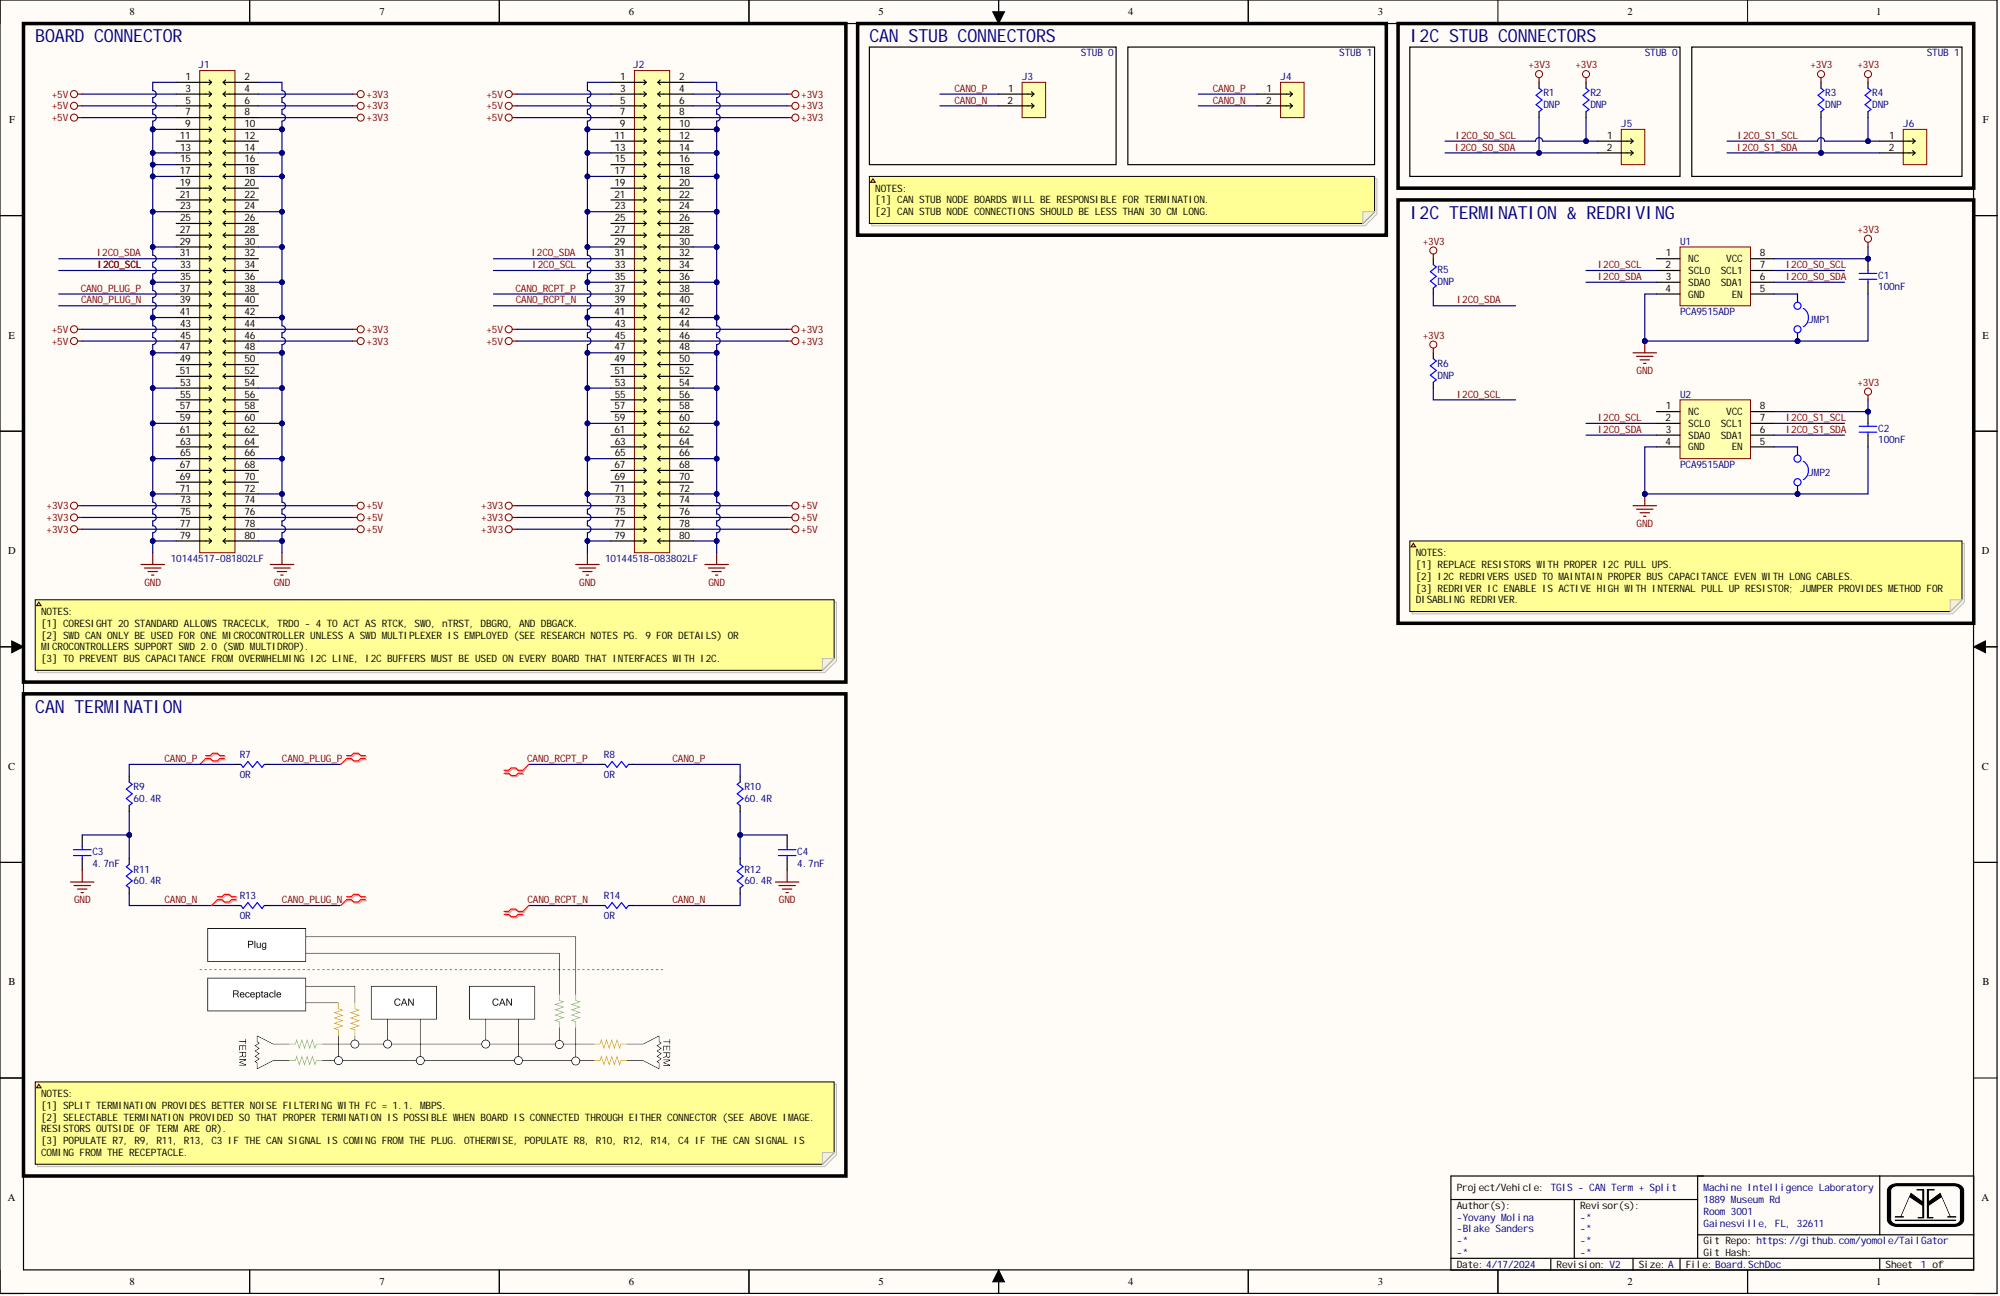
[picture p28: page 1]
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

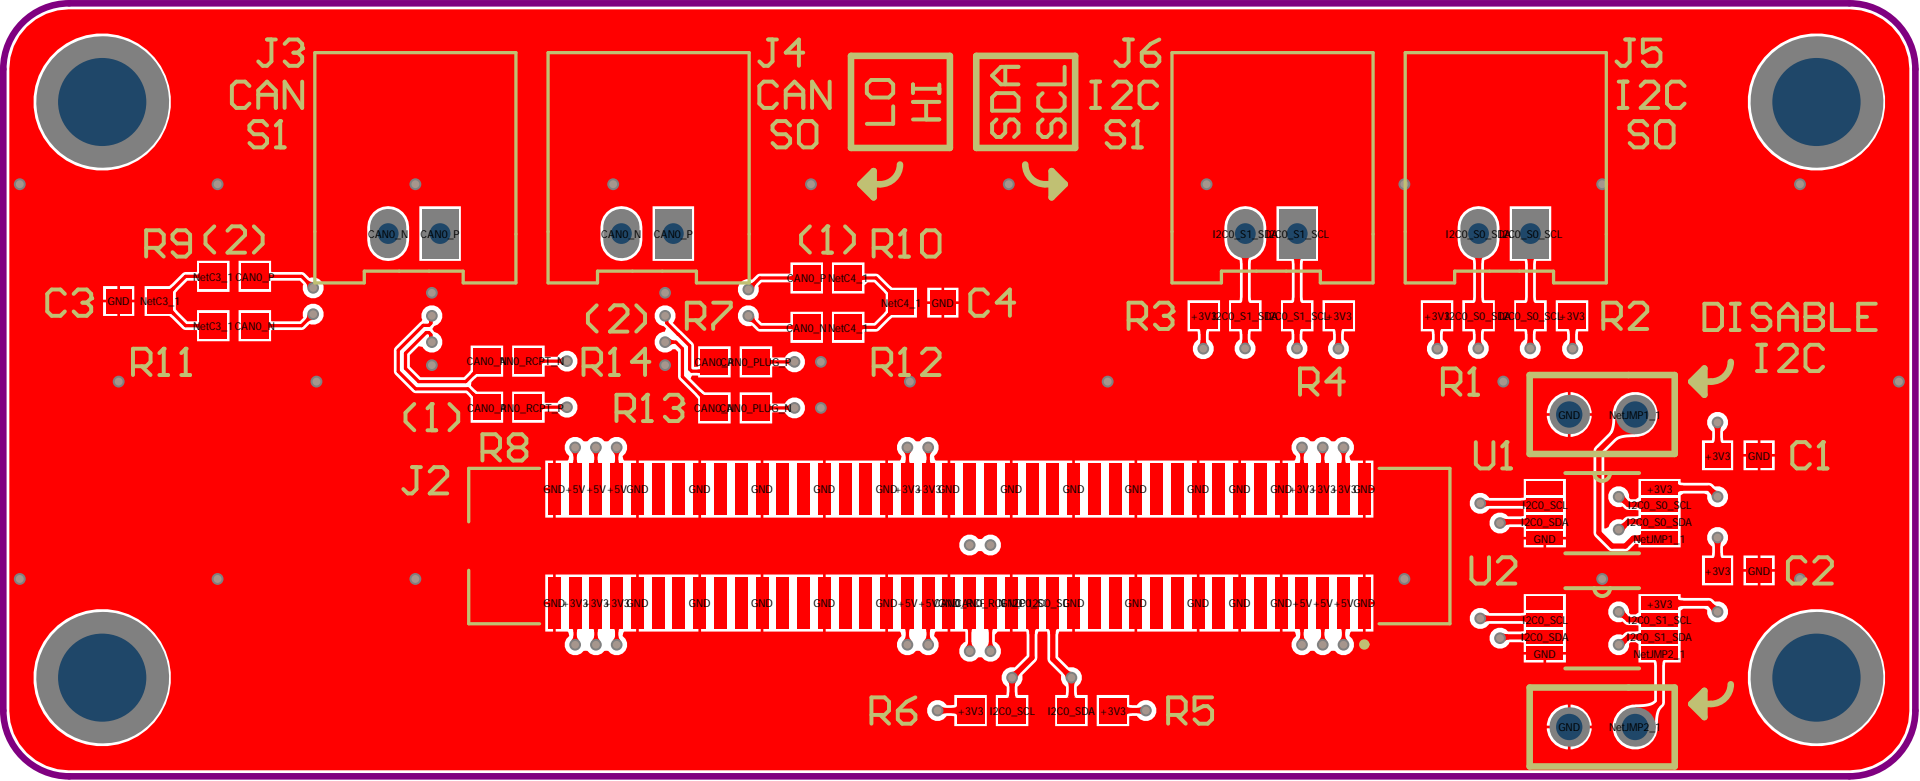
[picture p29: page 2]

I2C0_SCL | I2C0_S1_SCL

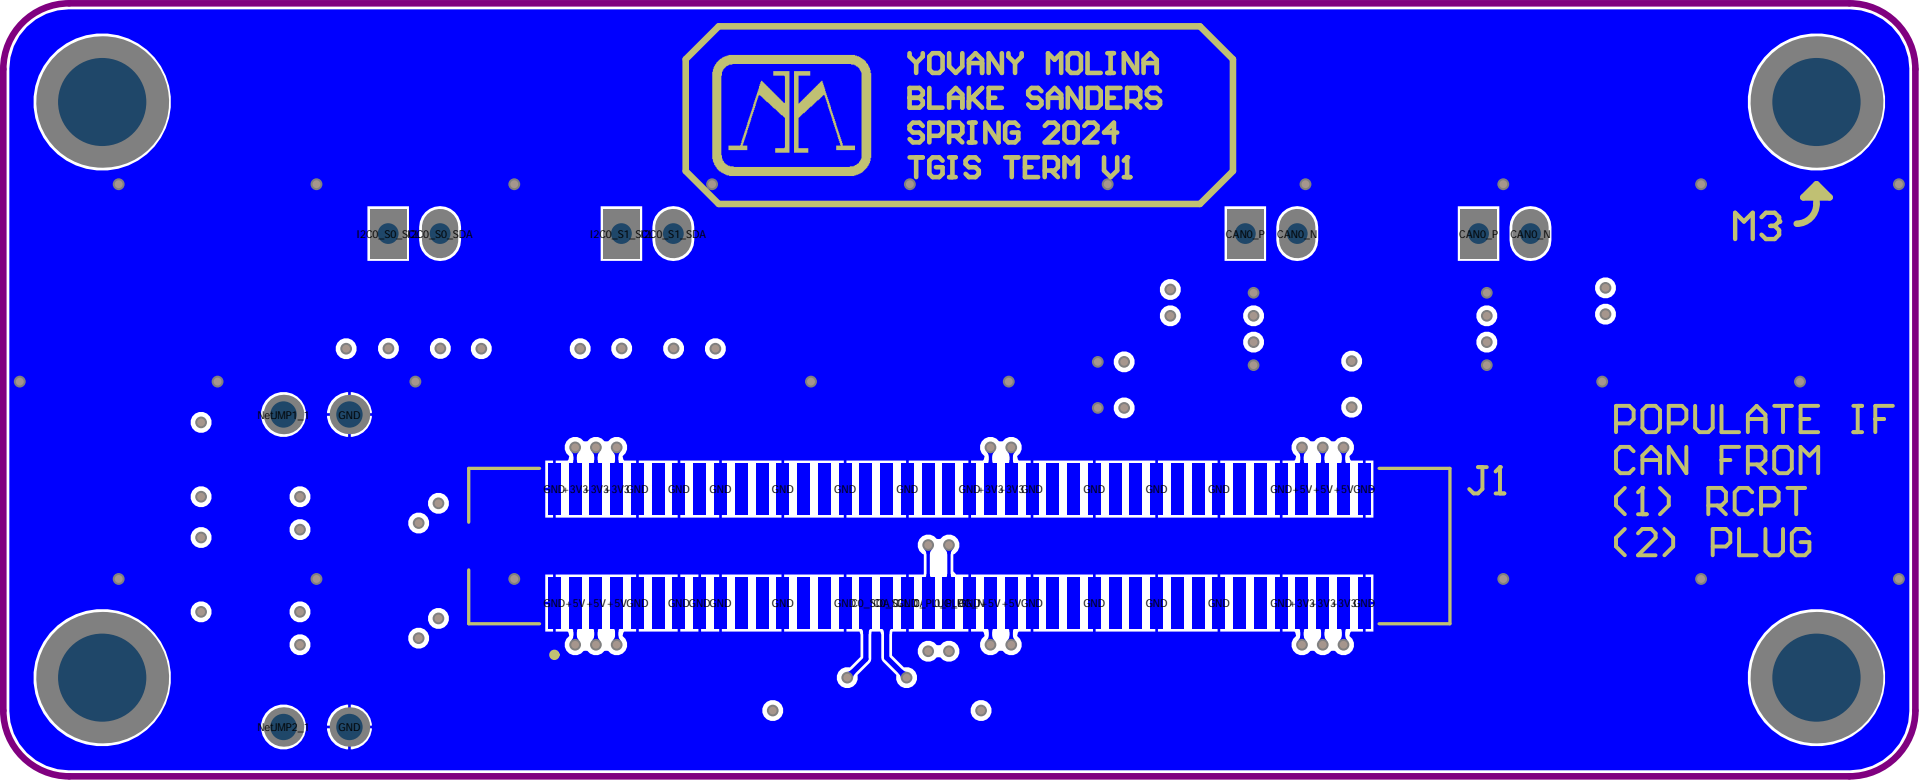
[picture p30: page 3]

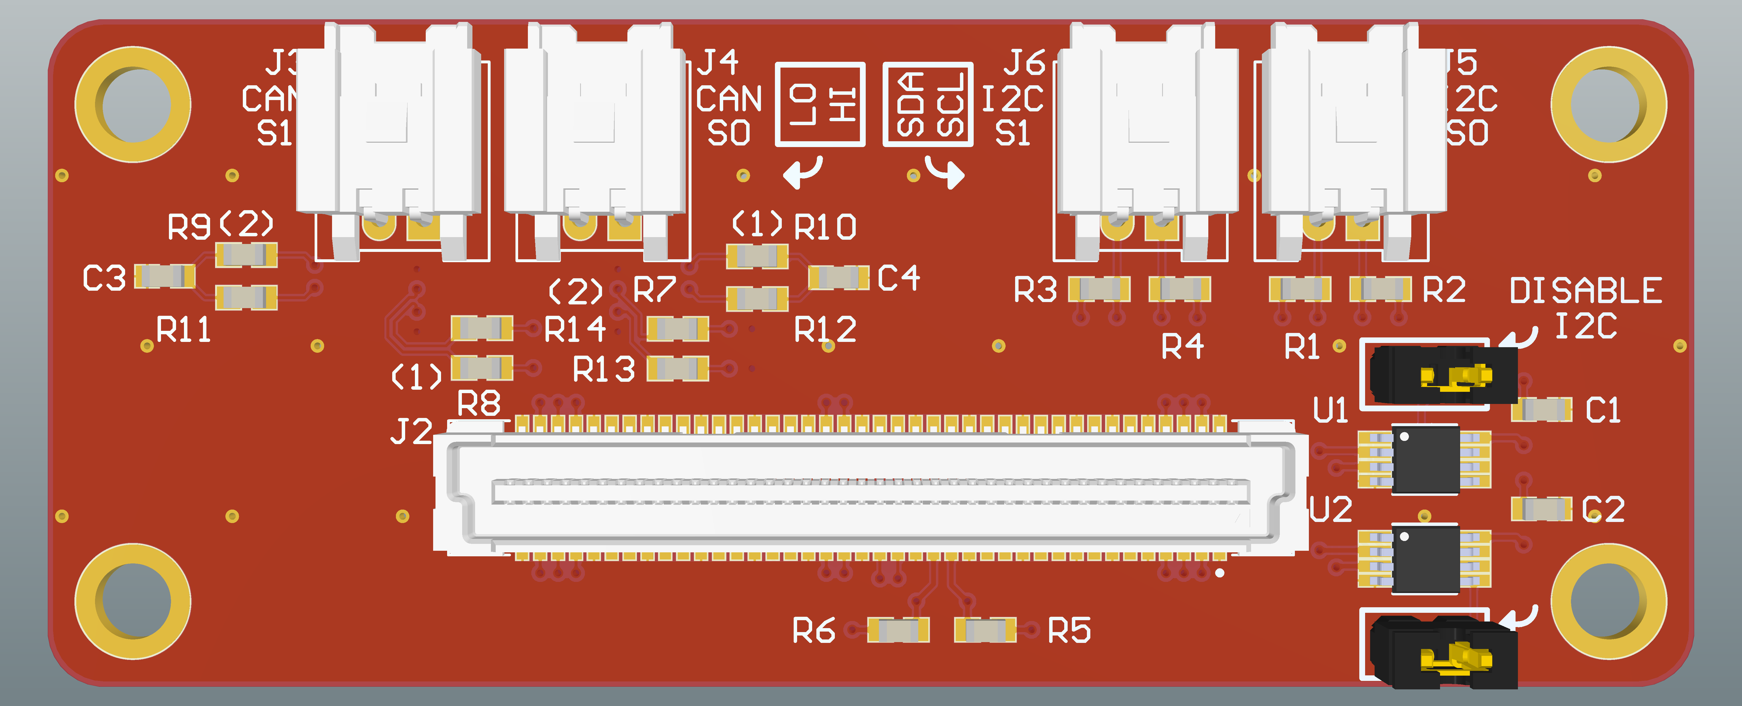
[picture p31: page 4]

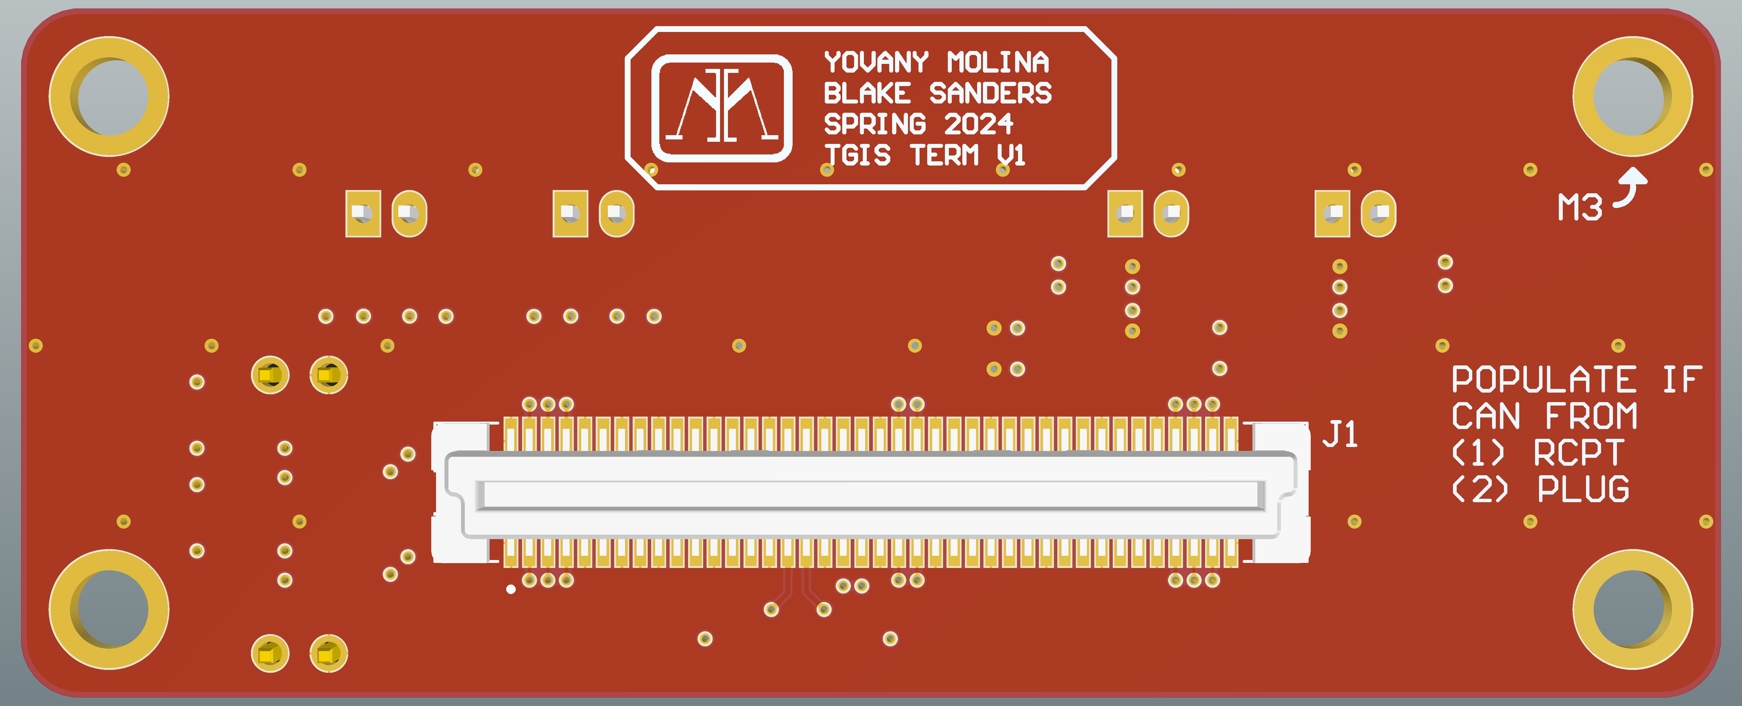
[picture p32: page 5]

Comment | Description | Designator | Footprint | LibRef | Quantity
100nF | Ceramic Capacitor, Multilayer, Cera | C1, C2 | CAPC0603 | CC0603KRX7R7BB104 | 2
4.7nF | Ceramic Capacitor, Multilayer, Cera | C3, C4 | CAPC0603 | CC0603JPX7R9BB472 | 2
10144517-081802LF | CONNRCPT180POS SMDGOLD | J1 | AMPHENOL_1014451 7-081802LF | 10144517-081802LF | 1
10144518-083802LF | CONNPLUG380POS SMDGOLD | J2 | AMPHENOL_1014451 8-083802LF | 10144518-083802LF | 1
0353630260 | Header, Molex, 2mm PitchSherlock Header, SingleRow, Horizontal, 2Circuits, Length3.3mm, 0353630260 | J3, J4, J5, J6 | MOLEX-HDR-1X2-SHERLOCK-HORZ | SHERLOCK-1x2-RA | 4
DNP | (DONOTPLACE) Resistor | R1, R2, R3, R4, R5, R6 | RES0603 | Resistor_DNP | 6
0R | FixedResistor, Metal Glaze/thickF | R7, R8, R13, R14 | RES0603 | RC0603FR-070RL | 4
60.4R | FixedResistor, Metal Glaze/thickF | R9, R10, R11, R12 | RES0603 | RC0603FR-0760R4L | 4
PCA9515ADP | ICREDRIVERI2C2CH 8TSSOP | U1, U2 | SOP65P490X110-8N | PCA9515ADP | 2

# Electrical Rules Check Report

Class | Document | Message Successful Compile for TGIS CAN Termination.PrjPcb
Wednesday 17 Apr 2024 9:41:03 PM | Page 1 of 1

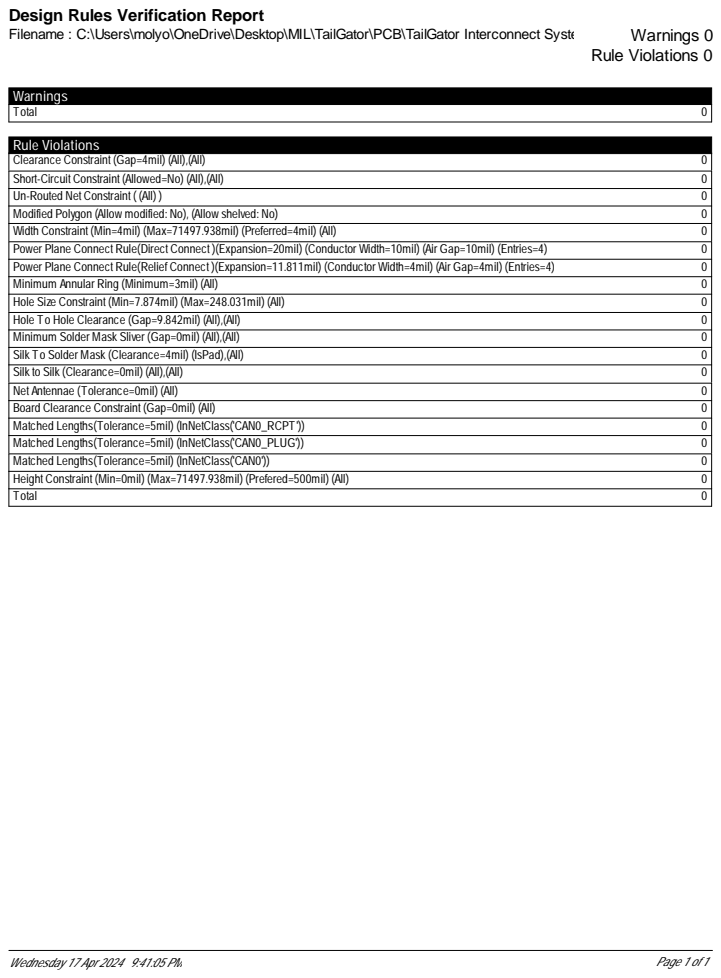
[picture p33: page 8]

Design Rules Verification Report

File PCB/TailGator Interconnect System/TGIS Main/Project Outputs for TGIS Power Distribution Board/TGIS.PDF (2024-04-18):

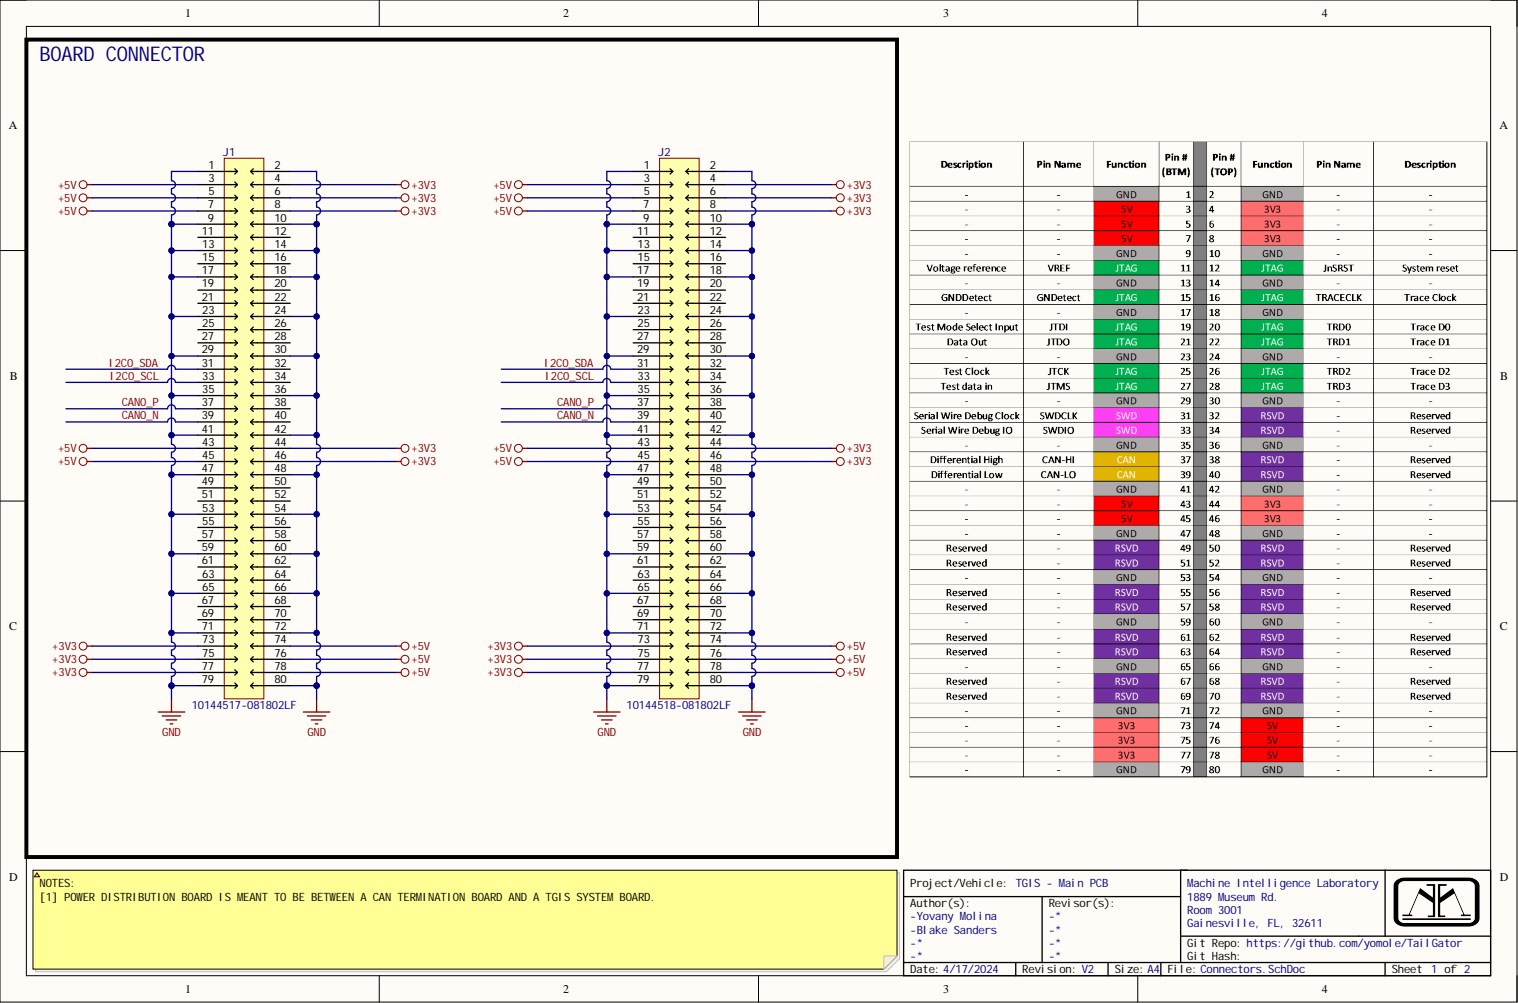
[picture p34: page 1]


NOTES:
[1] OVERVOLTAGE PROTECTION APPLIES AT VOLTAGES HIGHER THAN 3.5V AND 5.5V FOR 3.3V AND 5V
INPUTS.

NOTES: [1] SEE SIMULATION FOLDER FOR DETAILS. [2] FUSE HOLDER ACCEPTS 4A AUTOMOTIVE FUSE (E.G. https://www.napaonline.com/en/p/BK_7822086) PLACE NOTES BOX HERE [3] JUMPERS PROVIDED FOR BYPASSING PROTECTION DURING PROTOTYPING STAGE. THE PIN HEADER AND JUMPER SHOULD BE RATED FOR AT LEAST 4A (E.G. SNT-100-BK-T). | Project/Vehicle: TGIS - Main PCB | Machine Intelligence Laboratory 1889 Museum Rd Room 3001 Gainesville, FL, 32611

Author(s): -Yovany Molina -Blake Sanders -* -* | Revisor(s): -* -* -* -*

https://github.com/yomole/TailGator

Date: 4/17/2024 | Revision: V2 | Size: A | File: Power.SchDoc | Sheet 2 of 2





Comment | Description | Designator | Footprint | LibRef | Quantity
100nF | Ceramic Capacitor, Multilayer, Cera | C1, C2 | CAPC0603 | CC0603KRX7R7BB104 | 2
3V0 | DIODEZENER3.0V 500MWSOD123 | D1 | SOD3715X135N | BZT52C3V0 | 1
TN805 | SCR600V8A StandardRecovery SurfaceMount DPAK | D2, D4 | DPAK_TN | TN805-600B-TR | 2
4V7 | DIODEZENER4.7V 500MWSOD123 | D3 | SOD3715X135N | BZT52C4V7 | 1
YELLOW | SingleColor LED, Yellow, Water Cle | D5 | LED0603 | 150060YS75000 | 1
RED | SingleColor LED, Red, Water Clear, | D6 | LED0603 | 150060RS75000 | 1
FuseHolder | FuseHolder 30A500V 1Circuit Blade ThroughHole | F1, F2 | FUSE_3568 | 3568 | 2
10144517-081802LF | CONNRCPT180POS SMDGOLD | J1 | AMPHENOL_1014451 7-081802LF | 10144517-081802LF | 1
10144518-081802LF | CONNPLUG180POS SMDGOLD | J2 | AMPHENOL_1014451 8-081802LF | 10144518-081802LF | 1
1877285-2 | | J3, J4 | TE_1877285-2 | 1877285-2 | 2
AONR21321 | P-Channel 30V24A (Tc) 4.1W(Ta), 24W (Tc)SurfaceMount 8-DFN-EP(3x3) | Q1, Q2 | TRANS_AONR21321 | AONR21321 | 2
3.3kR | FixedResistor, Metal Glaze/thickF | R1, R2 | RES0603 | RC0603FR-073K3L | 2
1kR | FixedResistor, Metal Glaze/thickF | R3, R4 | RES0603 | RC0603FR-071KL | 2

# Electrical Rules Check Report

Class | Document | Message Successful Compile for TGIS Power Distribution Board.PrjPcb
Wednesday 17 Apr 2024 9:46:17 PM | Page 1 of 1


Design Rules Verification Report

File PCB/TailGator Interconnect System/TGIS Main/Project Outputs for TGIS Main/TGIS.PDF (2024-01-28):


NOTES: PLACE NOTES BOX HERE | Project/Vehicle: TGIS - Main PCB | Machine Intelligence Laboratory 1889 Museum Rd. Room 3001 Gainesville, FL, 32611

Author(s): -Yovany Molina -Blake Sanders -* -* | Revisor(s): -* -* -* -*

https://github.com/yomole/TailGator

Date: 1/18/2024 | Revision: - | Size: A | File: Connectors.SchDoc | Sheet 1 of 2


NOTES:
[1] POWER RAILS NEED VOLTAGES 0.6V HIGHER THAN THEIR RAILS BECAUSE OF PROTECTION
CIRCUITS.
[2] OVERVOLTAGE PROTECTION APPLIES AT VOLTAGES HIGHER THAN 4.5V AND 6V FOR 3.3V AND 5V
INPUTS.

NOTES: [1] SEE SIMULATION FOLDER FOR DETAILS. [2] FUSE HOLDER ACCEPTS 4A AUTOMOTIVE FUSE (E.G. https://www.napaonline.com/en/p/BK_7822086) PLACE NOTES BOX HERE [3] JUMPERS PROVIDED FOR BYPASSING PROTECTION DURING PROTOTYPING STAGE. THE PIN HEADER AND JUMPER SHOULD BE RATED FOR AT LEAST 4A (E.G. SNT-100-BK-T). | Project/Vehicle: TGIS - Main PCB | Machine Intelligence Laboratory 1889 Museum Rd Room 3001 Gainesville, FL, 32611

Author(s): -Yovany Molina -Blake Sanders -* -* | Revisor(s): -* -* -* -*

https://github.com/yomole/TailGator

Date: 1/18/2024 | Revision: A | Size: A | File: Power.SchDoc | Sheet 2 of 2





Comment | Description | Designator | Footprint | LibRef | Quantity
Cap | | C1, C2 | CAPC0603 | Cap | 2
3V0 | DIODEZENER3.0V 500MWSOD123 | D1 | SOD3715X135N | BZT52C3V0 | 1
TN805 | SCR600V8A StandardRecovery SurfaceMount DPAK | D2, D4 | DPAK_TN | TN805-600B-TR | 2
4V7 | DIODEZENER4.7V 500MWSOD123 | D3 | SOD3715X135N | BZT52C4V7 | 1
FuseHolder | FuseHolder 30A500V 1Circuit Blade ThroughHole | F1, F2 | FUSE_3568 | 3568 | 2
10144517-081802LF | CONNRCPT180POS SMDGOLD | J1 | AMPHENOL_1014451 7-081802LF | 10144517-081802LF | 1
1877285-2 | | J2, J3 | TE_1877285-2 | 1877285-2 | 2
LED | | LED1, LED2 | LED0603 | LED | 2
AONR21321 | P-Channel 30V24A (Tc) 4.1W(Ta), 24W (Tc)SurfaceMount 8-DFN-EP(3x3) | Q1, Q2 | TRANS_AONR21321 | AONR21321 | 2
Res | | R1, R2, R3, R4 | RES0603 | Res | 4
TP | | TP1, TP2, TP3, TP4, TP5, TP6, TP7, TP8, TP9, TP10, TP11, TP12 | TPTH-100mil | TP | 12

# Electrical Rules Check Report

Class | Document | Message Successful Compile for TGIS Main.PrjPcb
Thursday 18 Jan 2024 8:48:44 PM | Page 1 of 1


Design Rules Verification Report

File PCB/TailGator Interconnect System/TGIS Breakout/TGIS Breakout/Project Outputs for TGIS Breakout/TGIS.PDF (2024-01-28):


1 0
1 1






Comment | Description | Designator | Footprint | LibRef | Quantity
10144518-081802LF | CONNPLUG180POS SMDGOLD | J1 | AMPHENOL_1014451 8-081802LF | 10144518-081802LF | 1

PREC012DAAN-RC | Connector Header ThroughHole24 position0.100" (2.54mm) | J2, J3 | PREC012DAAN-RC | PREC012DAAN-RC | 2

# Electrical Rules Check Report

Class | Document | Message Successful Compile for TGIS Breakout.PrjPcb
Thursday 18 Jan 2024 9:12:35 PM | Page 1 of 1


Design Rules Verification Report
Filename : C:\Users\molyo\OneDrive\Desktop\MIL\TailGator\PCB\TailGator Interconnect Syste
m\TGIS Breakout\TGIS Breakout\Breakout.PcbDoc

Matched Lengths(Tolerance=5mil) (InNetClass('CAN0'))
Matched Net Lengths: Between Net CAN0_N And Net CAN0_P Actual Difference against CAN0_P is: 26.406mil, Tolerance : 5mil.

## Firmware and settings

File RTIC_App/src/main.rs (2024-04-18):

#![no_std]
#![no_main]

use rtic::app;
use defmt_rtt as _;
use panic_halt as _;

// Second-stage bootloader ------------------------------------------------------------------------
#[link_section = ".boot2"]
#[no_mangle]
#[used]
pub static BOOT2_FIRMWARE: [u8; 256] = rp2040_boot2::BOOT_LOADER_GD25Q64CS;

// RTIC App ---------------------------------------------------------------------------------------
#[app(device = rp2040_hal::pac, peripherals = true, dispatchers = [RTC_IRQ])]
mod app {
    // Debug imports
    use defmt::{trace, info, warn, error};

    // Peripheral sharing imports
    use core::cell::RefCell;
    use critical_section::Mutex;
    use embedded_hal_bus::i2c::CriticalSectionDevice as I2cCriticalSectionDev;

    // Board specific imports
    use rp2040_hal as hal;
    use rp2040_hal::pac as pac;

    const XOSC_CRYSTAL_FREQ: u32 = 12_000_000;

    use hal::{
        Clock,
        clocks::init_clocks_and_plls,
        watchdog::Watchdog,
        Sio,
        gpio::bank0::{
            Gpio22,     // I2C1 Sda
            Gpio23,     // I2C1 Scl
            Gpio13,     // LED
            Gpio18,     // SPI0 SCK
            Gpio19,     // SPI0 MOSI
            Gpio20,     // SPI0 MISO
            Gpio1,      // Leak Detector
            Gpio2,      // Leak Alarm
            Gpio17,     // SPI0 CS
        },
        gpio::{
            Pin,
            FunctionI2C,
            FunctionSpi,
            FunctionSioInput,
            FunctionSioOutput,
            PullUp,
            PullDown,
            PullNone,
        },
        i2c::I2C,
        spi::Spi,
        // pio::PIOExt,
    };

    // GPIO pin imports
    use embedded_hal::digital::{
        InputPin,
        OutputPin,
        StatefulOutputPin
    };

    // GPIO pin type aliases
    type LedPin = Pin<
        Gpio13,
        FunctionSioOutput,
        PullDown>;

    type LeakDetectorPin = Pin<
        Gpio1,
        FunctionSioInput,
        PullUp>;

    type LeakAlarmPin = Pin<
        Gpio2,
        FunctionSioOutput,
        PullDown>;

    // Timing imports
    use fugit::RateExtU32;

    // OLED imports
    use sh1107::{
        prelude::*,
        mode::GraphicsMode,
        interface::i2c::I2cInterface,
        Builder
    };

    use embedded_graphics::{
        mono_font::{
            ascii::FONT_6X9 as font,
            MonoTextStyleBuilder,
        },
        primitives::{
            Line,
            PrimitiveStyle,
        },
        pixelcolor::BinaryColor,
        prelude::*,
        text::Text
    };

    // OLED type aliases
    type Scl = Pin<Gpio23, FunctionI2C, PullUp>;
    type Sda = Pin<Gpio22, FunctionI2C, PullUp>;
    type I2cWithPins = I2C<pac::I2C1, (Sda, Scl)>;
    type OledDisplay = GraphicsMode<I2cInterface<I2cCriticalSectionDev<'static, I2cWithPins>>>;

    // IMU imports
    use lis3dh::{Lis3dh, Lis3dhI2C, SlaveAddr};
    use lis3dh::accelerometer::Accelerometer;
    use accelerometer::vector::VectorExt;


    // IMU type aliases
    type I2cBus = Mutex<RefCell<I2cWithPins>>;
    type Lis3dhAccelerometer = Lis3dh<Lis3dhI2C<I2cCriticalSectionDev<'static, I2cWithPins>>>;


    // SdCard imports
    use embedded_sdmmc::{SdCard, TimeSource, Timestamp, VolumeIdx, VolumeManager};
    use embedded_sdmmc::sdcard::DummyCsPin;
    use embedded_sdmmc::filesystem::Mode;
    use embedded_hal_bus::spi::{ExclusiveDevice, NoDelay};

    // Dummy timesource for creating files
    #[derive(Default)]
    pub struct DummyTimesource();

    impl TimeSource for DummyTimesource {
        fn get_timestamp(&self) -> Timestamp {
            Timestamp {
                year_since_1970: 0,
                zero_indexed_month: 0,
                zero_indexed_day: 0,
                hours: 0,
                minutes: 0,
                seconds: 0,
            }
        }
    }

    // SdCard type aliases
    type Spi0Bus = hal::Spi<
        hal::spi::Enabled,
        hal::pac::SPI0,
        (   Pin<Gpio19, FunctionSpi, PullNone>,
            Pin<Gpio20, FunctionSpi, PullUp>,
            Pin<Gpio18, FunctionSpi, PullNone>)
    >;
    type SdCardReader = SdCard<
        ExclusiveDevice<
            Spi0Bus,
            DummyCsPin,
            NoDelay>,
        Pin<Gpio17, FunctionSioOutput, PullDown>,
        hal::Timer
    >;
    type SdCardVolumeMgr = embedded_sdmmc::VolumeManager<
        SdCardReader, 
        DummyTimesource, 
        4, 4, 1
    >;



    // Resources ----------------------------------------------------------------------------------
    #[shared]
    struct DataShared {
        accel: Option<Lis3dhAccelerometer>,
        display: Option<OledDisplay>,
        
        accel_mag: f32,
        leak_detected: bool,
    }

    #[local]
    struct DataLocal {
        // Components
        led_pin: LedPin,
        leak_detector_pin: LeakDetectorPin,
        leak_alarm_pin: LeakAlarmPin,
        pixel: (u8, u8),
        dirs: (bool, bool),
        sd_card_volume_mgr: Option<SdCardVolumeMgr>,
    }

    // Systick magic
    use systick_monotonic::ExtU64;
    #[monotonic(binds = SysTick, default = true)]
    type MyMono = systick_monotonic::Systick<1000>;

    // Init function ------------------------------------------------------------------------------
    #[init(local = [i2c_bus: Option<I2cBus> = None])]
    fn init(cx: init::Context) -> (DataShared, DataLocal, init::Monotonics) {
        
        info!("initializing");

        let mut resets = cx.device.RESETS;
        let mut watchdog = Watchdog::new(cx.device.WATCHDOG);
        let clocks = init_clocks_and_plls(
            XOSC_CRYSTAL_FREQ,
            cx.device.XOSC,
            cx.device.CLOCKS,
            cx.device.PLL_SYS,
            cx.device.PLL_USB,
            &mut resets,
            &mut watchdog,
        )
        .ok()
        .unwrap();

        // GPIO setup -----------------------------------------------------------------------------
        let sio = Sio::new(cx.device.SIO);
        // initialize the pins to default state
        let pins = hal::gpio::Pins::new(
            cx.device.IO_BANK0,
            cx.device.PADS_BANK0,
            sio.gpio_bank0,
            &mut resets,
        );
        let led_pin = pins.gpio13.into_push_pull_output();
        let leak_detector_pin = pins.gpio1.into_pull_up_input();
        let leak_alarm_pin = pins.gpio2.into_push_pull_output();

        // Peripheral setup -----------------------------------------------------------------------

        // I2C
        let scl = pins.gpio23.into_function::<FunctionI2C>().into_pull_type::<PullUp>();
        let sda = pins.gpio22.into_function::<FunctionI2C>().into_pull_type::<PullUp>();
        let i2c1 = I2C::i2c1(
            cx.device.I2C1,
            sda,
            scl,
            fugit::RateExtU32::kHz(400),
            &mut resets,
            &clocks.system_clock,
        );
        let i2c_bus: &'static _ =
            cx.local.i2c_bus.insert(
                critical_section::Mutex::new(RefCell::new(i2c1))
            );

        // OLED display
        let oled_i2c = I2cCriticalSectionDev::new(i2c_bus);
        let display_size = DisplaySize::Display64x128;
        let display_rot  = DisplayRotation::Rotate270;
        let mut disp: GraphicsMode<_> = Builder::new()
            .with_size(display_size)
            .with_rotation(display_rot)
            .connect_i2c(oled_i2c)
            .into();
        let mut display: Option<OledDisplay> = None;
        match disp.init() {
            Ok(_)   => { trace!("OLED init succeeded"); display = Some(disp); },
            Err(e)  => error!("OLED init failed: {}", defmt::Debug2Format(&e)),
        }

        // IMU
        let lis3dh_i2c = I2cCriticalSectionDev::new(i2c_bus);
        let mut lis3dh: Option<Lis3dhAccelerometer> = None;
        match Lis3dh::new_i2c(lis3dh_i2c, SlaveAddr::Default) {
            Ok(imu) => { trace!("IMU init suceeded"); lis3dh = Some(imu) },
            Err(e)  => error!("IMU init failed: {}", defmt::Debug2Format(&e)),
        }
        if let Some(ref mut imu) = lis3dh {
            match imu.set_range(lis3dh::Range::G8) {
                Ok(_)   => trace!("IMU set range succeeded"),
                Err(e)  => error!("IMU set range failed: {}", defmt::Debug2Format(&e))
            };
        }


        // SPI
        let spi_sclk: Pin<_, FunctionSpi, PullNone> = pins.gpio18.reconfigure();
        let spi_mosi: Pin<_, FunctionSpi, PullNone> = pins.gpio19.reconfigure();
        let spi_miso: Pin<_, FunctionSpi, PullUp> = pins.gpio20.reconfigure();
        let spi_cs = pins.gpio17.into_push_pull_output();

        let spi_bus = Spi::<_, _, _, 8>::new(cx.device.SPI0, (spi_mosi, spi_miso, spi_sclk));

        let spi_bus = spi_bus.init(
            &mut resets,
            clocks.peripheral_clock.freq(),
            400.kHz(), // card initialization happens at low baud rate
            embedded_hal::spi::MODE_0,
        );

        let spi_device = ExclusiveDevice::new(spi_bus, DummyCsPin, NoDelay);

        let delay = rp2040_hal::Timer::new(
            cx.device.TIMER,
            &mut resets,
            &clocks,
        );

        // SD Card reader
        let sdcard = SdCard::new(spi_device, spi_cs, delay);
        let mut v_mgr = VolumeManager::new(sdcard, DummyTimesource::default());
        let mut volume_mgr: Option<SdCardVolumeMgr> = None;
        
        match v_mgr.device().num_bytes() {
            Ok(size) => { info!("SD card size is {} bytes", size); volume_mgr = Some(v_mgr) },
            Err(e) => {
                error!("Error retrieving card size: {}", defmt::Debug2Format(&e));
            }
        }

        if let Some(ref mut volume_mgr) = volume_mgr {
            volume_mgr
                .device()
                .spi(|spi_device| spi_device.bus_mut().set_baudrate(clocks.peripheral_clock.freq(), 16.MHz()));
        }

        // Task setup -----------------------------------------------------------------------------
        info!("Spawning tasks...");
        blink::spawn(5).unwrap();

        // Start IMU communication
        update_imu::spawn().unwrap();

        // Start leak detection
        update_leak_detector::spawn_after(1000.millis()).unwrap();

        // Start OLED animation
        update_oled::spawn_after(2000.millis()).unwrap();
        
        // Start heartbeat
        heartbeat::spawn_after(3000.millis()).unwrap();

        // Test logging to SD card
        test_log::spawn_after(3200.millis()).unwrap();

        // Return the resources
        (
            DataShared {
                accel: lis3dh,
                display: display,
                
                accel_mag: 0.0f32,
                leak_detected: false,
            },
            DataLocal {
                led_pin: led_pin,
                leak_detector_pin: leak_detector_pin,
                leak_alarm_pin: leak_alarm_pin,
                pixel: (10, 25),
                dirs: (true, true),
                sd_card_volume_mgr: volume_mgr,
            },
            init::Monotonics(systick_monotonic::Systick::new(cx.core.SYST, 125_000_000)),
        )
    }


   
    // Heartbeat task -----------------------------------------------------------------------------
    #[task]
    fn heartbeat(_cx: heartbeat::Context) {
        trace!("heartbeat");
        blink::spawn(1).unwrap();

        heartbeat::spawn_after(1000.millis()).unwrap();
    }

    // LED blink task -----------------------------------------------------------------------------
    const BLINK_DUR: u64 = 120;  // = on_time = off_time (in ms)
    #[task(local = [led_pin])]
    fn blink(cx: blink::Context, n: u8) {
        if n == 0 {
            return;
        } else if cx.local.led_pin.is_set_low().unwrap() {
            cx.local.led_pin.set_high().unwrap();
            blink::spawn_after(BLINK_DUR.millis(), n).unwrap();
        } else {
            cx.local.led_pin.set_low().unwrap();
            blink::spawn_after(BLINK_DUR.millis(), n-1).unwrap();
        }
    }

    // Leak detector task -------------------------------------------------------------------------
    #[task (shared=[leak_detected], local=[leak_detector_pin, leak_alarm_pin])]
    fn update_leak_detector(cx: update_leak_detector::Context) {
        // Read the pin
        let leak = cx.local.leak_detector_pin.is_low().unwrap();

        // Update status
        if leak { warn!("leak pin high! leak detected!"); cx.local.leak_alarm_pin.set_high().unwrap(); } 
        else { trace!("leak pin low"); cx.local.leak_alarm_pin.set_low().unwrap(); }

        // Update shared resource
        let mut leak_detected = cx.shared.leak_detected;
        leak_detected.lock(|leak_detected_l| {*leak_detected_l = leak});

        update_leak_detector::spawn_after(500.millis()).unwrap();
    }

    // OLED update task ---------------------------------------------------------------------------
    const FEATHER_DISPLAY_SIZE: Size = Size::new(128, 64);
    const START_POSITION_1: Point = Point::new(0, font.character_size.height as i32 - 3);
    const SEPARATOR_POSITION: Point = Point::new(START_POSITION_1.x, START_POSITION_1.y + 4);
    const START_POSITION_2: Point = Point::new(SEPARATOR_POSITION.x, SEPARATOR_POSITION.y + font.character_size.height as i32);
    const START_POSITION_3: Point = Point::new(START_POSITION_2.x, START_POSITION_2.y + font.character_size.height as i32);
    
    const VIBRATION_THRESHOLD: f32 = 2.0f32;
    
    #[task(shared = [display, accel_mag, leak_detected], local = [pixel, dirs])]
    fn update_oled(cx: update_oled::Context) {
        // Change these values to view the interface prototypes //
        let num_can_devices: u8 = 1;                            //
        // ---------------------------------------------------- //

        // 0 = nominal, 1 = warn, 2 = err
        let mut system_state = 0;
        if num_can_devices == 0 { system_state = 1;}
        
        let mut leak_detected = cx.shared.leak_detected;
        let mut is_leak = false;
        leak_detected.lock(|leak_l| { is_leak = *leak_l; });
        if is_leak { system_state = 2; }

        // Font styles
        let normal = MonoTextStyleBuilder::new()
            .font(&font)
            .text_color(BinaryColor::On)
            .build();

        let underline = MonoTextStyleBuilder::from(&normal)
            .underline()
            .build();

        let highlight = MonoTextStyleBuilder::from(&normal)
            .background_color(BinaryColor::On)
            .text_color(BinaryColor::Off)
            .build();


        let mut d = cx.shared.display;
        d.lock(|d_l| {
            if let Some(ref mut d_l) = d_l {
                
                // Clear the display buffer
                d_l.clear();

                // Process system state
                let mut position = Point::new(0, 0);
                match Text::new("Status: ", START_POSITION_1, normal).draw(d_l) {
                    Ok(pos) => position = pos,
                    Err(e) => error!("{}", defmt::Debug2Format(&e))
                };
                match system_state {
                    0 => match Text::new("nominal", position, normal).draw(d_l) { Ok(_) => (), Err(e) => error!("{}", defmt::Debug2Format(&e))},
                    1 => match Text::new("warning", position, underline).draw(d_l) { Ok(_) => (), Err(e) => error!("{}", defmt::Debug2Format(&e))},
                    2 => match Text::new("critical", position, underline).draw(d_l) { Ok(_) => (), Err(e) => error!("{}", defmt::Debug2Format(&e))},
                    _ => match Text::new("", position, normal).draw(d_l) { Ok(_) => (), Err(e) => error!("{}", defmt::Debug2Format(&e))},
                };

                // Draw a separating line
                match Line::new(
                    SEPARATOR_POSITION, 
                    Point::new(SEPARATOR_POSITION.x + FEATHER_DISPLAY_SIZE.width as i32, SEPARATOR_POSITION.y))
                    .into_styled(PrimitiveStyle::with_stroke(BinaryColor::On, 1))
                    .draw(d_l) {
                    Ok(_) => (),
                    Err(e) => error!("{}", defmt::Debug2Format(&e)),
                };

                // List the number of CAN devices
                // Note we expect to have 3-4 devices in practice, so fully supporting up to 10 (with partial support for more) is sufficient
                match Text::new("CAN devices: ", START_POSITION_2, normal).draw(d_l) {
                    Ok(pos) => position = pos,
                    Err(e) => error!("{}", defmt::Debug2Format(&e)),
                }

                let can_dev_msg = match num_can_devices {
                    0 => "0", 1 => "1", 2 => "2", 3 => "3", 4 => "4", 5 => "5", 6 => "6", 7 => "7", 8 => "8", 9 => "9", 10 => "10",
                    _ => ">10"
                };
                match Text::new(can_dev_msg, position, normal).draw(d_l) {
                    Ok(_) => (),
                    Err(e) => error!("{}", defmt::Debug2Format(&e)),
                }

                // Vibration detection
                let mut vibration_detected = false;
                let mut accel_mag = cx.shared.accel_mag;
                accel_mag.lock(|accel_mag_l| {
                    if *accel_mag_l < VIBRATION_THRESHOLD { trace!("acceleration magnitude: {:?}", accel_mag_l); }
                    else { warn!("Vibration detected! Magnitude: {:?}", accel_mag_l); vibration_detected = true; }

                });
            
                // Order implies priority
                if is_leak {
                    match Text::new("LEAK DETECTED!", START_POSITION_3, highlight).draw(d_l) {
                            Ok(_) => (),
                            Err(e) => error!("{}", defmt::Debug2Format(&e)),
                    }
                } else if vibration_detected {
                    match Text::new("Vibration detected!", START_POSITION_3, underline).draw(d_l) {
                        Ok(_) => (),
                        Err(e) => error!("{}", defmt::Debug2Format(&e)),
                    }
                }

                match d_l.flush() {
                    Ok(_) => { trace!("OLED flush succeeded"); },
                    Err(e) => {error!("OLED flush failed: {}", defmt::Debug2Format(&e))},
                };
            }
        });
        update_oled::spawn_after(50.millis()).unwrap();
    }


    // IMU update task ----------------------------------------------------------------------------
    #[task(shared = [accel, accel_mag])]
    fn update_imu(cx: update_imu::Context) {
        let mut accel = cx.shared.accel;
        accel.lock(|accel_l| {
            if let Some(ref mut accel_l) = accel_l {
                let mut accel_mag = cx.shared.accel_mag;
                accel_mag.lock(|accel_mag_l| {
                    match accel_l.accel_norm() {
                        Ok(accel_vec)   => {
                            *accel_mag_l = accel_vec.magnitude();
                            trace!("accel magnitude: {:?}", *accel_mag_l);
                        },
                        Err(e)  => warn!("unable to read accel from IMU: {}", defmt::Debug2Format(&e)),
                    };
                });
            }
        });
        update_imu::spawn_after(1000u64.millis()).unwrap();
    }

    // Write a test message to a log file via the volume manager. ---------------------------------
    #[task(local = [sd_card_volume_mgr])]
    fn test_log(cx: test_log::Context) {
        trace!("Getting SD card volume 0...");
        if let Some(ref mut volume_mgr) = cx.local.sd_card_volume_mgr {
            let mut volume = match volume_mgr.open_volume(VolumeIdx(0)) {
                Ok(v) => v,
                Err(e) => {
                    error!("Error getting volume 0: {}", defmt::Debug2Format(&e));
                    loop{}
                }
            };
    
            let mut dir = match volume.open_root_dir() {
                Ok(dir) => dir,
                Err(e) => {
                    error!("Error opening root dir: {}", defmt::Debug2Format(&e));
                    loop{}
                }
            };
    
            let _file = match dir.open_file_in_dir("log.txt", Mode::ReadWriteCreateOrTruncate) {
                Ok(mut file) => {
                    match file.write(b"test log data") {
                        Ok(_) => info!("Wrote successfully to file!"),
                        Err(e) => error!("{}", defmt::Debug2Format(&e)),
                    }
                }
                Err(e) => {
                    error!("Error opening file 'log.txt': {}", defmt::Debug2Format(&e));
                    loop{}
                }
            };
        }
        
    }
} // mod app

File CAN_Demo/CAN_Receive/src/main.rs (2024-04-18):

#![no_std]
#![no_main]

/**** low-level imports *****/
use core::fmt::Write;
use core::panic::PanicInfo;
// use panic_halt as _;
// use cortex_m::prelude::*;
// use cortex_m_rt::entry;
use embedded_hal::{
    digital::v2::{OutputPin},
};


// CAN BUS --------------------------------------------------------------------
extern crate alloc;

use embedded_can::nb::Can;
use embedded_can::{Frame, StandardId};
// use embedded_hal::digital::StatefulOutputPin;
// use panic_probe as _;
// use panic_halt as _;
use rp2040_hal as hal;
use rp2040_hal::clocks::init_clocks_and_plls;
use rp2040_hal::gpio::Pins;
use rp2040_hal::{entry, pac, pac::interrupt, Sio, Watchdog};
use rp_pico::XOSC_CRYSTAL_FREQ;
// const XOSC_CRYSTAL_FREQ: u32 = 12_000_000;

use can2040::global_allocator::init_allocator;
use can2040::CanFrame;

const CONFIG_CANBUS_FREQUENCY: u32 = 10_000;
const CONFIG_RP2040_CANBUS_GPIO_RX: u32 = 8;
const CONFIG_RP2040_CANBUS_GPIO_TX: u32 = 7;
// ----------------------------------------------------------------------------

// USB Device support
use usb_device::class_prelude::*;
// USB Communications Class Device support
mod usb_manager;
use usb_manager::UsbManager;
// Global USB objects & interrupt
static mut USB_BUS: Option<UsbBusAllocator<hal::usb::UsbBus>> = None;
static mut USB_MANAGER: Option<UsbManager> = None;
#[allow(non_snake_case)]
#[interrupt]
unsafe fn USBCTRL_IRQ() {
    match USB_MANAGER.as_mut() {
        Some(manager) => manager.interrupt(),
        None => (),
    };
}
#[panic_handler]
fn panic(panic_info: &PanicInfo) -> ! {
    if let Some(usb) = unsafe { USB_MANAGER.as_mut() } {
        writeln!(usb, "{}", panic_info).ok();
    }
    loop {}
}

#[entry]
fn main() -> ! {
    init_allocator();

    // Grab the singleton objects
    let mut pac = pac::Peripherals::take().unwrap();
    let mut core = pac::CorePeripherals::take().unwrap();
    // Init the watchdog timer, to pass into the clock init
    let mut watchdog = Watchdog::new(pac.WATCHDOG);
    let clocks = init_clocks_and_plls(
        XOSC_CRYSTAL_FREQ,
        pac.XOSC,
        pac.CLOCKS,
        pac.PLL_SYS,
        pac.PLL_USB,
        &mut pac.RESETS,
        &mut watchdog,
    ).ok().unwrap();
    
    // Setup USB
    let usb = unsafe {
        USB_BUS = Some(UsbBusAllocator::new(hal::usb::UsbBus::new(
            pac.USBCTRL_REGS,
            pac.USBCTRL_DPRAM,
            clocks.usb_clock,
            true,
            &mut pac.RESETS,
        )));
        USB_MANAGER = Some(UsbManager::new(USB_BUS.as_ref().unwrap()));
        // Enable the USB interrupt
        pac::NVIC::unmask(hal::pac::Interrupt::USBCTRL_IRQ);
        USB_MANAGER.as_mut().unwrap()
    };

    // initialize the Single Cycle IO
    let sio = Sio::new(pac.SIO);
    // initialize the pins to default state
    let pins = Pins::new(
        pac.IO_BANK0,
        pac.PADS_BANK0,
        sio.gpio_bank0,
        &mut pac.RESETS,
    );

    use rp2040_hal::Clock;
    // let mut timer = cortex_m::delay::Delay::new(core.SYST, clocks.system_clock.freq().to_Hz());
    let mut led_pin = pins.gpio13.into_push_pull_output();



    let mut can_bus = can2040::initialize_cbus(
        &mut core,
        CONFIG_CANBUS_FREQUENCY,
        CONFIG_RP2040_CANBUS_GPIO_RX,
        CONFIG_RP2040_CANBUS_GPIO_TX,
    );


    let mut count = 0u64;
    let mut packet_num = 0u64;

    /*
    Loop Section
    */
    let delay: u32 = 500;   // loop delay in ms
    let mut n: u32 = 0;
    loop {
        if n % 1_000_000 == 13 {
            // write!(usb, "starting loop number {:?}\r\n", n).unwrap();
            led_pin.set_low().unwrap();
            // Await CAN packet
            match can_bus.receive() {
                Ok(f) => {
                    // info!("Received packet: {:?}", f.data()[3]);
                    write!(usb, "Received data: {:?}\r\n", f.data()[3]);
                }
                // Err(nb::Error::Other(err)) => {
                //     // error!("Errors in reading CAN frame, {:?}", err);
                // }
                _ => () // ignore
            }

            // timer.delay_ms(delay as u32);
            led_pin.set_high().unwrap();
            // timer.delay_ms(delay as u32);
            
        }
        n = n + 1;
    }

}

pub fn create_frame(cob_id: u16, data: u64) -> CanFrame {
    CanFrame::new(
        StandardId::new(cob_id).expect("error in create standard id"),
        &[1, 2, 3, (data & 0xff) as u8],
    )
    .expect("error in create_frame")
}

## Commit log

2023-11-05 Initial commit of work for pre-alpha. Added connectors for JTAG, power, CAN, and USB.
    [TIS Main PCB.PrjPcb]
2023-11-05 Supporting files for Pre-Alpha
    [10144517-061x0xxx.step, 10144517-061x0xxx.stp, 10144518-062x0xxx.stp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]
2023-11-06 Add I2C testing project for pre-alpha
2023-11-27 PCB design and protection circuit work
    [MainPCB.PcbDoc, MainPCB.SchDoc, Protoboard.PcbDoc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]
2023-11-27 OLED interface prototype code
2024-01-07 Minor updates to schematic metadata
    [MainPCB.SchDoc]
2024-01-10 Entire first draft of the schematic with the new connector pinout.
    [Connectors.SchDoc, TGIS Breakout.PrjPcb]
2024-01-10 Entire first draft of the schematic with the new mezzanine connector and pinout.
    [Connectors.SchDoc, MainPCB.PcbDoc, Microcontroller.SchDoc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]
2024-01-10 Major work on project and updates to documentation
    [10144517-061x0xxx.step, 10144517-061x0xxx.stp, 10144517-081802LF NoPeg.step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]
2024-01-11 Finished breakout board for testing. Needs labels and DFM check
    [Breakout.PcbDoc, Breakout.SchDoc, TGIS Breakout.PrjPcb]
2024-01-28 Complete and Order V1 of some boards - USB to CAN, Power Input, and Breakout board V1 are finished and ordered. - Additions and Modifications to TGIS libraries and research notes. - Autodeletion of o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
    [10144518-082802LF NoPeg.step, 10144518-082802LF.STEP, 10144518-083802LF NoPeg.step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]
2024-01-29 Update README.md
    Ð̶͉͉̲̳͆̓͊̈́̇͜ð̶͍̦͖͔͙̀̽̀̅̕¢̴̨̻͈͙̖͆͆̀̉̈́µ̵̩͕̗͕̠͌̔̃͋̍m̴͈̭̹̟̜͋̐͗́͝ê̸̪̖̖̲͍̈́̾͑̍̕ñ̸̺͈̻͙͙̒̌̓̌̈́†̸̛̹͈̘̘̙͋̿́͠å̷̢͍͕̤̪̈́̾̒̆͐†̵̧̧͖̩̭̈͛̀̎̓ï̴̢̛̛̫͉̥̳̃͂͊ð̶̖̥̰̜͇̐̒̍̈̏ñ̶̬̤̬̰͆̑̍̔̃ͅ ̵̧̹̼̬̲̾̔̿͋̃£̶̨̫͈̜̳̀̄̔̋͝ð̵̻̘̗͓͚̔̓͌̏͊r̷͗̽̏͑͘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
2024-01-30 Revert accidental modification during cleanup (Sorry Blake!)
    [main.rs]
2024-02-04 Make BOM for boards - Edit schematics, PCBs, and libraries to make Altium BomDocs behave. - Export BOMs to xlsx. - Move gitignore one folder up so it affects Library/History.
    [Connectors.SchDoc, MainPCB.PcbDoc, Microcontroller.SchDoc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]
2024-02-25 V1 Hardware Testing
    [Connectors.SchDoc, ovp-data-2024.02.25_16.23.02.csv, rpp-data-2024.02.25_16.11.30.csv]
2024-02-26 add leak detector pin
    [main.rs]
2024-03-23 implement shared i2c bus
2024-03-24 error handling but oled is broken currently
    [main.rs]
2024-03-24 oled code worked hahaha so funny oled wire bad
2024-03-25 add error handling to update_imu()
    [main.rs]
2024-03-25 Add prototype display interface
2024-03-25 clean up error handler
    [main.rs]
2024-03-25 Work work work work work work
    [Board.PcbDoc, Board.SchDoc, Breakout.PcbDoc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]
2024-04-02 Finish 2nd board order
    [BOM V2 Combined.xlsx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]
2024-04-08 implement vibration detection lesgooooooooooooo
    [main.rs]
2024-04-08 restructure leak detection and integrate with OLED
    [main.rs]
2024-04-17 reconfigure to physical System Status Board
2024-04-18 Modified BOM, Add PCB documentation
    [BOM V2 Combined.xlsx]
2024-04-18 Update README.md
    Added documentation for system status and termination boards.
2024-04-18 remove C USB to CAN prototype project

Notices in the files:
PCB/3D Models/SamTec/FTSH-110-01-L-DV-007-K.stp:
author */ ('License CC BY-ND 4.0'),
